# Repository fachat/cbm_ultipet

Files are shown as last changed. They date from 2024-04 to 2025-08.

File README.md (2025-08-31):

# Ulti-PET

Note: this is a part of a larger set of repositories, with [upet_family](https://github.com/fachat/upet_family) as the main repository.

This is a re-incarnation of the Commodore PET computer(s) from the later 1970s.

It is build on a PCB that fits into a C64-II case (with extra cutouts for connectors), and has only parts that can still be obtained new in 2024/2025.
A 3D-printed case is also available specific for the Ulti-PET PCB.

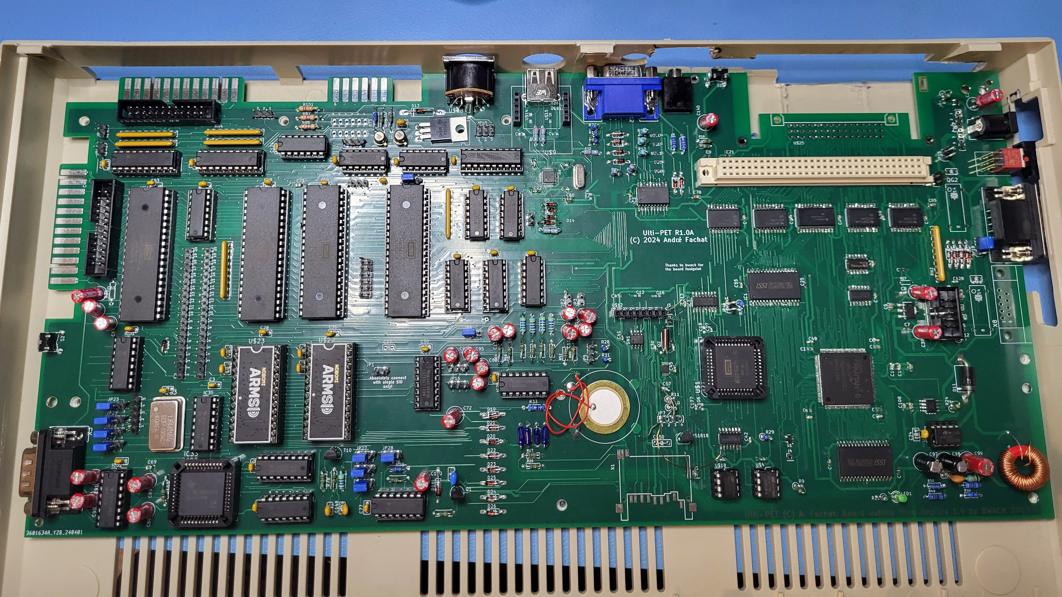
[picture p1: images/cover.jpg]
Picture of a Ulti-PET


Videos on the machine are coming soon on the [YouTube 8-bit times](https://youtube.com/playlist?list=PLi1dzy7kw1iybjcUccgjCV4fhNH4IPWSx) channel.

## Features

The board is built with a number of features:

- Commodore 3032 / 4032 / 8032 / 8296 with options menu to select at boot
  - Boot-menu to select different PET versions to run (BASIC 1, 2, 4)
  - 40 and 80 col character display
  - 8296 memory map emulation
  - IEEE488 interface (card edge and 24pin flat ribbon cable)
  - Tape connector (card edge, incl. 9V for proper tape operation)
  - PET graphics keyboard, or alternatively a C64 keyboard
- Improved system design:
  - 512k video RAM, plus 512k fast RAM, accessible using banks on the W65816 CPU
  - boot from an SPI Flash ROM
  - up to 13.5 MHz mode (via configuration register)
  - Write protection for the PET ROMs once copied to RAM
  - lower 32k RAM mappable from all of the 512k fast RAM
  - single 5V power supply (<1A) using USB-C connector
  - hardware and firmware support SD-Card and USB keyboard or mouse
- Improved Audio output:
  - Original beeper sound
  - Audio output using a DAC with DMA
  - Dual SID output
  - beeper, DAC, and SID are mixed into a stereo line output
  - integrated amplifier can drive <1W speakers
- Improved Video output:
  - VGA colour video output (222 RGB)
  - up to 96x72 characters on screen
  - hires modes up to a 720x576 resolution
  - Dual 16 out of 64 colour palette, Colour-PET or C128 VDC-compatible, Sprites
  - Hires graphics mode (using a configuration register)
  - modifyable character set
  - multiple video pages mappable to $8000 video mem address
- Extra I/O features:
  - Userport Joystick, software-switchable between single and dual joystick configs
  - fast serial IEC for Commodore's 1581 or 1571 disk drives (ROM support TBD)
  - 5V SPI interface for further extensions
  - 3.3V SPI interface for further extensions
  - Adafruit(tm) UEXT interface for further extensions (SPI shared with 3.3V SPI, includes I2C)
  - Dual UART serial, one RS232, one TTL (shared with UEXT, or the USB-C-to-serial)

## Overview

The system architecture is actually rather simple, as you can see in the following graphics.

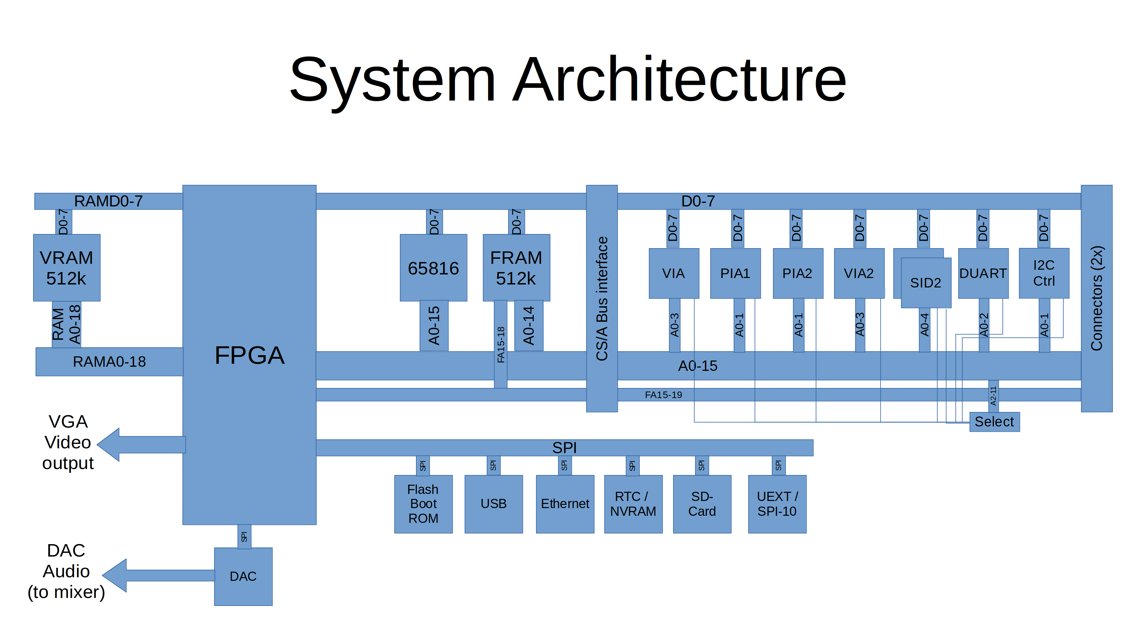
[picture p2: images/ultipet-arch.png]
Ulti-PET System Architecture


The main functionality is "hidden" inside the FPGA. It does:

1. clock generation and management
2. memory mapping
3. video generation.
4. SPI interface and boot
5. DAC DMA

On the CPU side of the FPGA it is actually a rather almost normal 65816 computer, 
with the exception that the bank register (that catches and stores the address lines 
A16-23 from the CPU's data bus) is in the FPGA, and that there is no ROM. The ROM has been
replaced with some code in the FPGA that copies the initial program to the CPU accessible
RAM, taking it from the Flash Boot ROM via SPI. This actually simplifies the design,
as 

1. parallel ROMs are getting harder to come by and
2. they are typically not as fast as is needed, and
3. with the SPI boot they don't occupy valuable CPU address space.

The video generation is done using time-sharing access to the video RAM.
The VGA output is 720x576 at 50Hz, or 720x480 at 60 Hz. So there is a pixel clock of 27MHz.

The system runs at 13.5MHz, so a byte of pixel output (i.e. eight pixels) has four
memory accesses to VRAM. Two of them are reserved for video access, one for fetching the
character data (e.g. at $08xxx in the PET), and the second one to fetch the "character ROM"
data, i.e. the pixel data for a character. This is also stored in VRAM, and is being loaded
there from the Flash Boot ROM by the initial boot loader.

The FPGA reads the character data, stores it to fetch the character pixel data, and streams
that out using its internal video shift register.

For more detailled descriptions of the features and how to use them, pls see the 
[FPGA repository](https://github.com/fachat/upet_fpga) that contains the code for the FPGA,
as described in the next section.

## I/O included in the Ulti-PET

The Ulti-PET not just has the Ultra-CPU, but also loads of I/O on the one board:

### Standard PET IO

The Ulti-PET includes the standard PET I/O features using the VIA and two PIAs, with some extensions. So, it has:

- IEEE488, including flat ribbon cable and card edge connector; with the additional capability of working as a device too
- Tape#1 (incl. 9V for proper tape operation), incl. card edge connector
- Tape#2 as TTL, but normally re-used for IEEE488 device handling
- PET keyboard, with the option to use a C64 keyboard, and the extended Ultipet-Keyboard
- PET userport, with the Video signal (optionally) replaced with 5V to accomodate user port extensions; incl. card edge connector
- Joystick connectors for the userport, software-switchable between single- or dual mode (compatible with 'stupid pet tricks')
- Reset and diag push buttons

### RS232

A Dual UART chip provides two serial interfaces. One interface is a real RS232 with a
DB9 connector. The other one is TTL level interface (shared with UEXT, see below).

The USB-C power connector has an USB-to-serial converter, that can be jumpered to the 
TTL level interface.

### Fast IEC

An IEC interface is provided using a second VIA chip. Using the VIA shift register, fast mode IEC
(like in the C128) is implemented.

### Dual SID and sound mixer

Two SID chips are included for your stereo sound pleasure.

The two SID outputs are mixed with the DAC audio output from the Ultra-CPU base.
Also, the beeper sound is mixed into the overall sound output.

Two audio amps are included to, so speakers can be directly connected to the board
(switched off when the audio jack is used).

### Keyboard shift lock and reset

When the shift-lock key in the replacement keyboard is defined on a specific position in 
the keyboard matrix (as is in the keyboard designed by Steve Gray), the key works like a shift-lock key.

In addition, pressing the shift-lock key longer (a few seconds), resets the machine 
(as long as the keyboard scanning still works).

### CS/A expansion board

The board has a full width CS/A slot for a single expansion card, plus a short CS/A board for
the accompanying [CS/A Ultrabus]() Ultra-Bus expansion board. This allows using (compatible)
Apple-II, RC2014, and C64 cartridges with the Ulti-PET.

(Older versions up to 1.2a had a problem there that is now fixed!)

### UEXT, and SPI-10 connectors

The board provides three standard I/O ports:

1. UEXT - this includes serial (see above), I2C, and SPI, all in 3.3V
2. SPI-10-3.3V - a 3.3V SPI interface for external modules (shared with UEXT)
3. SPI-10-5V - a 5V SPI interface provided by the second VIA, with selectable clock mode.

For the SPI-10 connectors see [here](http://forum.6502.org/viewtopic.php?f=4&t=4264&start=15#p48167).
For the UEXT connector see the Olimex [UEXT page](https://www.olimex.com/Products/Modules/UEXT/)

## Firmware features

Of the modern I/O, currently these are included and supported in the firmware, i.e. in the
BASIC4 models:

- USB keyboard or mouse support, if you select the boot option with a USB keyboard
- SD-Card support using the SD-Card filesystem from the Commander X16 provided by Michael Steil.
- C64 compatible kernal jump table

Note that if you select the boot option while holding the left shift key, a second optional 
configuration is being used.
For more details see the [ROM](https://github.com/fachat/upet_roms) repository, that contains
the current version of the firmware and accompanying documentation.
 
## Known Issues

The current revision is 1.3A

The known issues from the 1.2A version have been fixed.

A small number of non-functional issues has been found and documented. See the
[github list of issues](https://github.com/fachat/cbm_ultipet/issues?q=is%3Aissue%20state%3Aopen%20label%3Ar1.3a).

## Revision history

1.3a: Update:
- fixes for 1.2a known issues included, including improved audio mixer
- USB-C power supply connector, with USB-to-serial converter that can be connected to the internal 2nd serial port
- footprints for Joysticks improved and moved inwards
- footprint for VGA connector improved
- extended keyboard connector with I2C, and other lines
- extended pin header connectors for RS232
- improved pinout on FPGA to prep for HDMI (video output on differential pairs)
- optional pulldowns on audio out for original SIDs
- (most) THT parts have proper part numbers for JLCPCB for outsourced assembly too, not just SMD

1.2a: Update
- separate 3.3V generation for the bus, USB, and network, more bypass for SD cards
- Power, Shift Lock LED
- Remove 2nd oscillator option
- Digital video out connector for further experimentation
- Fix addressing of 2nd SID
- Replace some 1N4148 with 1N4448 for lower drop voltage, fix joystick diode direction
- Dual voltage divider for TTL beeper to avoid left/right audio crosstalk
- Fixes on the UART

1.1a: Update:
- Fixed userport joystick handling, allow software switching between single- and dual mode
- Include the beeper into the sound mixer
- Move from single UART to dual UART, to provide TTL serial or serial for UEXT
- Add I2C controller for UEXT
- Add UEXT, SPI-10-3.3V, SPI-10-5V connectors
- Add SPI interface with selectable modes on the second VIA (shares shift register with fast serial IEC bus)

1.0a: Initial release

## Building

Here are the subdirectories:

- [Board](Board/) that contains the board schematics and layout

Note that a case for the Ulti-PET is in the works - the case modifications for the Micro-PET do *not* work.

In addition, two other repositories are needed - they are separate as they are shared with other variants of the upet-family:

- [FPGA](https://github.com/fachat/upet_fpga) contains the VHDL code to program the FPGA logic chip used, and describes the configuration options - including the SPI usage, the DAC usage, and the Video features.
- [ROM](https://github.com/fachat/upet_roms) ROM contents to boot

### Board

To have the board built, you can use the gerbers that are stored in the zip file in the Board/production subdirectory.

To populate the board, there is an interactive bom (bill of materials) from KiCad, as well as the KiCad BOM CSV export in the [bom](Board/bom/) folder.

Parts numbers can be found in the [BOM list](Board/bom/cbm_ultipet_v1.2a-bom.xlsx). It has parts numbers for Mouser for all parts (except the SID), 
and for JLCPCB for the SMD parts. You can have JLCPCB assemble most of the SMD parts, and order the rest from Mouser. (Note, to not order parts twice, best
remove the JLPCB assembled parts before you upload to Mouser).

The BOM contains an Ethernet breakout board that is put into the connectors "above" the USB port. As an alternative you could use the 
[Wifi breakout board](https://github.com/fachat/upet_wifi). Note that at this time, this is not tested / programmed yet.

As an audio solution I am planning to use the Visaton K40SQ speakers, if you want to order them as well.

### FPGA

The FPGA is a Xilinx Spartan 6 programmable logic chip. It runs on 1.2V with 3.3V I/O and I programmed it in VHDL.

To build the FPGA content, clone the [FPGA](https://github.com/fachat/upet_fpga) repository, and look for the ultipetx.yz.bin, where the x.yz should be replaced with the current board
version, or the highest FPGA version below the board version.
This needs to be programmed into the SPI flash chip containing the configration for the FPGA.

To actually modify the code, you have to download and install the Xilinx WebISE software and open the ultipetx.yz.xise project file.

### ROM

To build the boot ROM image, clone the [ROM](https://github.com/fachat/upet_roms) repository, and build the spiimg70m file. This needs to be 
programmed into the SPI flash ROM containing the 65816 boot code.

The ROM image can be built using gcc, xa65, and make. Use your favourite EPROM programmer to burn it into the SPI Flash chip.

The ROM contains images of all required ROM images for BASIC 1, 2, and 4, and corresponding editor ROMs, including
some that have been extended with wedges.

The updated editor ROMs are from [Steve's Editor ROM project](http://www.6502.org/users/sjgray/projects/editrom/index.html) and can handle C64 keyboards, has a DOS wedge included, and resets into the Micro-PET boot menu.
For more details see the description in the ROM repository.

### Case

Currently no custom case is publicly available. I just didn't have time to build / test / write up the ones I have on tinkercad. Contact me privately and I can provide you a link.

## Gallery (R1.0)

The boot menu

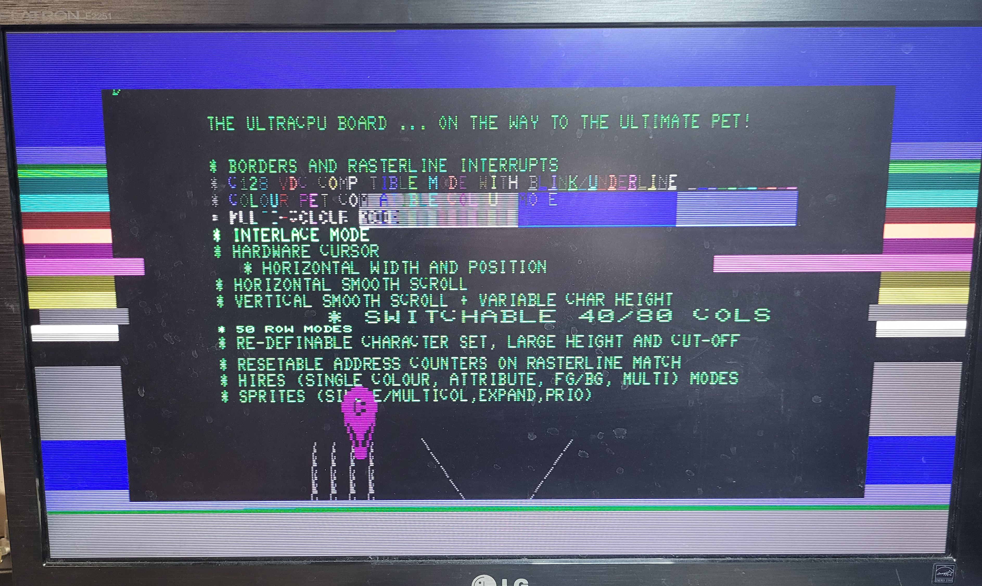
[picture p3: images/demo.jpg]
Demo of graphics capabilities


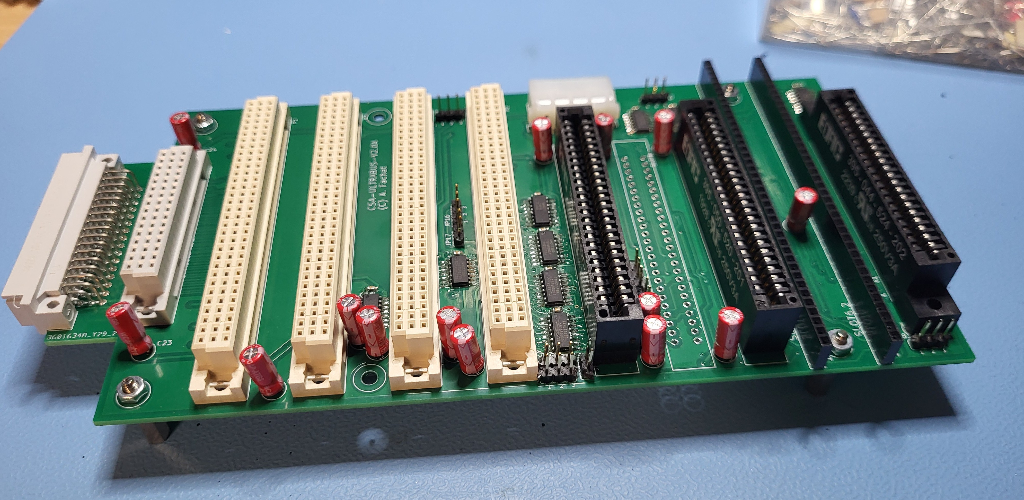
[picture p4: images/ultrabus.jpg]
Expansion bus


First showing the boot menu during the build process

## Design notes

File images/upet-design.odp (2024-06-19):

## System Architecture

A0-3

A0-1

A0-1

FA15-18

A0-15

D0-7

D0-7

D0-7

D0-7

D0-7

D0-7

D0-7

D0-7

SPI

SPI

SPI

SPI

SPI

SPI

SPI

D0-7

RAM
A0-18

D0-7

CS/A Bus interface

A0-3

A0-4

A0-2

A0-14

A0-1

Connectors (2x)

A2-11

RAMD0-7

FPGA

D0-7

VRAM

512k

65816

FRAM

512k

VIA

PIA1

PIA2

VIA2

SID1

SID2

DUART

I2C

Ctrl

RAMA0-18

VGA

Video

output

DAC

Audio

(to mixer)

A0-15

FA15-19

SPI

Select

Flash
Boot
ROM

USB

Ethernet

RTC /
NVRAM

SD-
Card

UEXT /

SPI-10

DAC

## Memory Map (boot)

ipl

ipl

CPU address space (lower 1M)

64k
bank0

Banks 0 … 7

Banks 8 … 15

64k
bank0

64k 8296

Ext. bank

Banks 2 … 7

64k video
bank

Banks 9 … 15

512k FRAM

Physical address space

The CPLD can only write (the IPL code from Flash) to VRAM, so the initial

Mapping maps VRAM to banks 0-7 of the CPU

512k VRAM

## Memory Map

CPU address space (lower 1M)

0-32k

32-
64k

Banks 1 … 15

Any of 16

32k blocks

In FRAM

4k
V

Bank 0, or

8296 mem expansion

In bank 1

Any of four 2k positions in video bank

8k
Chr

rom

8k
Chr

64k
bank0

64k 8296

Ext. bank

Banks 2 … 7

64k video
bank

Banks 9 … 15

512k FRAM

Physical address space

512k VRAM

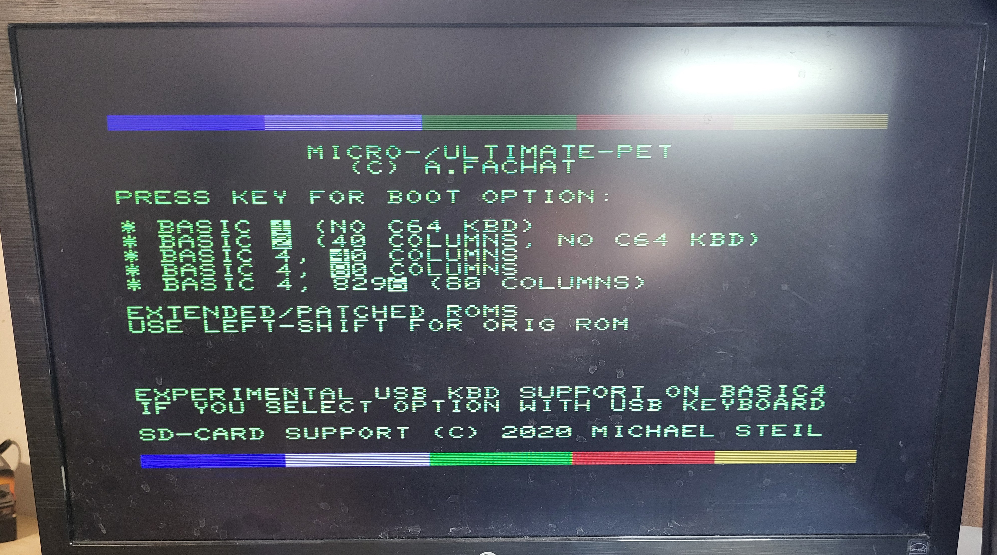
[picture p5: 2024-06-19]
images/boot_menu.jpg

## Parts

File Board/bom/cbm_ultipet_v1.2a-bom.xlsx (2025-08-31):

Id | Designator | Footprint | Quantity | Orig. Quantity | Designation | Supplier and ref | MOUSER | Manufac. Part | Alt. Mouser | Alt. Manufac. Part | JLCPCB Part #（optional）
 | SMD
81 | U$19 | TQFP144 | 1 |  | XC6SLX9-TQG144 |  | 217-XC6SLX9-2TQG144C | XC6SLX9-2TQG144C |  |  | C415799
68 | IC8 | PQFP-32_5x5mm_P0.5mm | 1 |  | MAX3421E |  | 700-MAX3421EEHJT | MAX3421EEHJ+T |  |  | C2651881
150 | Q4 | MICRO3 | 1 |  | IRLML5203 |  | 942-IRLML5203TRPBF | IRLML5203TRPBF |  |  | C2592
59 | SN1 | SOIC8 | 1 |  | MCP48X2 |  | 579-MCP4802-E/SN | MCP4802-E/SN |  |  | C144363
148 | U$13 | MSOP10 | 1 |  | MCP79510 |  | 579-MCP79510-I/MS | MCP79510-I/MS |  |  | C636437
70 | IC24 | TSSOP-20_4.4x6.5mm_P0.65mm | 1 |  | PCF9564 |  | 771-PCA9564PW118 | PCA9564PW,118
20 | C40,C29,C30,C39 | C0603 | 4 |  | 18p |  | 80-C0603C180K4HACTU | C0603C180K4HACTU |  |  | C152921
5 | C2, C11,C12,C13, C15,C16,C17,C18,C19, C22, C23, C25,C26,C27, C31,C32,C33,C34,C35, C41,C42,C43,C44,C45,C46,C47,C48, C58, C100,C101,C102,C103,C104,C105,C106,C107,C108,C109,C110,C111,C112,C113, C146, C147, C150,C7,C8,C63,C85,C127,C128,C152,C155 | C0603 | 53 |  | 0.1u |  | 710-885012206020 | 885012206020 |  |  | C14663
21 | C5,C67,C68,C69,C70,C71,C64,C65,C66,C154 | C0805 | 9 |  | 22u |  | 187-CL21A226MPQNNNE | CL21A226MPQNNNE |  |  | C5674
67 | C1,C4,C14,C24,C49,C54,C55,C56,C57,C120,C121,C123 | C0603 | 12 |  | 1u |  | 791-0603B105K6R3CT | 0603B105K6R3CT | 80-C0603X105J8R | C0603X105J8RACTU | C309479
 | U8 |  | 1 |  | 74ahct1g08 |  | 595-74AHCT1G08DBVRG4 | 74AHCT1G08DBVRG4 |  |  | C113521
109 | U1 | SOT-23-5 | 1 |  | 74LVC1G04 |  | 595-SN74LVC1G04DBVR | SN74LVC1G04DBVR |  |  | C7434171
93 | IC5,IC2,IC4 | SO20W@1 | 3 |  | 74245DW |  | 595-SN74HCT245DWR | SN74HCT245DWR |  |  | C132267
86 | IC16 | SO24L | 1 |  | 74LVC8T245SO24 |  | 595-SN74LVC4245ADW | SN74LVC4245ADW |  |  | C2677625
64 | IC19,IC13 | SO20W@1 | 2 |  | 74244DW |  | 595-SN74HCT244DWRG4 | SN74HCT244DWRG4 |  |  | C6776
49 | U5,U4 | SOIC-16 | 2 |  | CD4053B |  | 595-CD4053BNSR | CD4053BNSR |  |  | C6742
152 | IC14 | SO14 | 1 |  | 7414D |  | 595-SN74LV14ADR | SN74LV14ADR |  |  | C133541
57 | IC18 | SO14 | 1 |  | 7406D |  | 595-SN74LVC06ADR | SN74LVC06ADR |  |  | C7658
107 | IC7 | SO16 | 1 |  | 74138D |  | 771-74LVC138AD-T | 74LVC138AD,118 |  |  | C6061
72 | IC3 | SO14@1 | 1 |  | 74125D |  | 595-SN74LVC125AD | SN74LVC125AD |  |  | C6057
3 | U$16 | PSOP-8-FIXED | 1 |  | AP2132BB |  | 621-AP2132BMP1.2TRG1 | AP2132BMP-1.2TRG1 |  |  | C338874
116 | U$3,U$17 | SOT223 | 2 |  | LDI1117 |  | 637-LDI1117-3.3H | LDI1117-3.3H |  |  | C6186
38 | U$14,U$6,U$10,U$5,U$8,U$11,U$15 | SOD323 | 7 |  | ESDBIDIR |  | 771-PESD5V0L1BA-T/R | PESD5V0L1BA,115 |  |  | C2687118
63 | IC1,IC10 | SOP32 | 2 |  | RAMSOCK32TO512KSOP |  | 870-61C5128AS-25QLI | IS61C5128AS-25QLI
 | Pin header
4 | P2 | C64KEYB | 0 | 1 | C64KEYB
143 | P8 | C64KEYB | 0 | 1 | PETKEYBD
11 | JP17,JP2,JP6,JP15,JP18,JP11,JP9,JP4,JP12,JP3,JP1 | JP1 | 0 | 11 | JP1E
26 | JP8,JP5,JP13,JP27,JP29,JP31,JP26,JP14,JP20,JP16,JP28,JP24 | JP2 | 0 | 9 | JP2E
35 | J4,J5,J1,J3 | PinHeader_1x01_P2.54mm_Vertical | 0 | 4 | Conn_01x01_Pin
75 | U$26 | JP7 | 0 | 1 | JP7
77 | P6,P7 | JP6 | 0 | 2 | CBMTAPE
112 | JP7 | JP4 | 0 | 1 | JP4E
117 | U$27,U$2 | JP5 | 0 | 2 | JP5
 |  |  | 10 |  | pin strip straight 20 pin |  | 538-22-28-4204 | 22-28-4204 | 649-1012937892001BLF | 10129378-920001BLF
42 | P4,P9 | IDC-Header_2x05_P2.54mm_Vertical | 2 |  | ~ |  | 710-61201021621 | 61201021621
128 | J7 | IDC-Header_2x05_P2.54mm_Vertical | 1 |  | UEXT_Host |  | 710-61201021621 | 61201021621
151 | U$7 | FLAT10BOX | 1 |  | XILINXPROG (optional) |  | 710-61201021621 | 61201021621
78 | J8 | PinHeader_2x04_P2.54mm_Vertical | 0 | 1 | Conn_02x04_Odd_Even
139 | JP10 | JP3Q | 0 | 1 | JP3Q
 | P11 | PinHeader_2x06_P2.54mm_Vertical |  | 1
 |  |  | 1 |  |  |  | 649-1012938192001BLF | 10129381-920001BLF
142 | P3 | FLAT24 | 1 |  | IEEE488FLATCABLE |  | 710-61202421621 | 61202421621
95 | P5 | FLAT24 | 1 |  | PETUSERPORT |  | 710-61202421621 | 61202421621
85 | SJ1 | SJ_2 | 1 |  | SJ2W |  |  | Solder-Jumper, no part
130 | C114 | C025-024X044 | 1 |  | 1500p |  | 594-D152K25Y5PH63J5R | D152K25Y5PH63J5R
120 | C125 | C025-024X044 | 1 |  | 0.01, 50V |  | 594-K103K15X7RF5TH5 | K103K15X7RF5TH5 | flat disk
8 | C149,C148 | C025-024X044 | 2 |  | 0.01u |  | 594-K103K15X7RF5TH5 | K103K15X7RF5TH5 | flat disk
137 | C126 | C025-025X050 | 1 |  | 0.47 |  | 810-FA26X7R1H474KNU6 | FA26X7R1H474KNU06 | flat disk
25 | C138,C94,C133,C143,C124,C134,C137,C144,C131,C139,C141,C93,C92,C84,C135,C142,C73,C132,C145 | C025-024X044 | 19 |  | 100n |  | 594-K104K10X7RF53L2 | K104K10X7RF53L2 | 594-K104K15X7RF53H5 | K104K15X7RF53H5
33 | C74,C3,C77,C36,C76,C59,C62,C20,C50,C28,C10,C51,C52,C37,C53,C60 | C025-025X050 | 17 |  | 100n |  | 594-K104K10X7RF53L2 | K104K10X7RF53L2 | 594-K104K15X7RF53H5 | K104K15X7RF53H5
96 | C86,C90,C91,C87 | E2,5-6 | 4 |  | 1u |  | 710-860010772005 | 860010772005 | 710-860020672005 | 860020672005
 | C158,C159 | CP_Radial_D5.0mm_P2.50mm | 2 |  | 100u |  | 710-860010372006 | 860010372006
9 | C151,C61,C6,C153 | E2,5-6 | 4 |  | 47u |  | 710-860010372004 | 860010372004
 | C156,C157 | C_Disc_D5.0mm_W2.5mm_P5.00mm | 2 |  | 10u |  | 810-FG28X5R1E106MR06 | FG28X5R1E106MRT06
28 | C81,C79,C78,C80 | C025-025X050 | 4 |  | 22000 (only if real SIDs) |  | 594-K222K15X7RF5TH5 | K222K15X7RF5TH5
 | C129,C136 | C_Disc_D5.0mm_W2.5mm_P5.00mm | 2 |  | 1u MLCC |  | 810-FG28X5R1H105KRT0 | FG28X5R1H105KRT00
45 | C117,C96,C95,C116,C118,C115 | E2-5 | 6 |  | 1u (note: alternatively mlcc) |  | 810-FG28X5R1H105KRT0 | FG28X5R1H105KRT00 | 710-860020672005 | 860020672005
39 | C88,C89 | E2,5-6 | 2 |  | 4u7 |  | 710-860020472001 | 860020472001
134 | C130 | E2-4 | 1 |  | 10u |  | 710-860020372001 | 860020372001
103 | C83,C119,C82,C122 | E2-5 | 4 |  | 10u |  | 710-860020372001 | 860020372001
53 | C38 | E2,5-6 | 1 |  | 22u |  | 710-860010372002 | 860010372002
65 | C72,C75,C140 | E2,5-7 | 3 |  | 47u |  | 710-860010372004 | 860010372004
80 | C97,C98,C9,C21 | E2,5-7 | 4 |  | 100u |  | 710-860010372006 | 860010372006 | 667-EEU-FM1E101 | EEU-FM1E101
131 | C99 | E2,5-7 | 1 |  | 330u |  | 710-860020373011 | 860020373011
140 | L4 | TJ4-U2 | 1 |  | 200uH |  | 710-744115 | 744115
147 | L2 | 0204_7@1 | 1 |  | 1uH |  | 652-78F1R0K-TR-RC | 78F1R0K-TR-RC
6 | T6,T7 | TO92 | 2 |  | 2T2222 |  | 637-2N2222A | 2N2222A | 494-JAN2N2222A | Jan2N2222A
74 | Q1 | TO92 | 1 |  | BC557 |  | 512-BC557BTA | BC557BTA
125 | T10 | TO92 | 1 |  | BC547 |  | 512-BC547BTA | BC547BTA
135 | T8 | TO220 | 1 |  | TIP31 |  | 863-TIP31CG | TIP31CG
92 | R49 | 0204_7 | 1 |  | 0.22 |  | 603-MFR-25FTF52-0R22 | MFR-25FTF52-0R22
12 | R33 | 0207_10 | 1 |  | 10 |  | 603-MF0207FTE26-10R | MF0207FTE26-10R
24 | R2,R1,R4 | 0204_7 | 3 |  | 33 |  | 660-MF1/4LCT52R330J | MF1/4LCT52R330J
44 | R7,R8 | 0204V | 2 |  | 68 |  | 660-MF1/4LCT52R680G | MF1/4LCT52R680G
84 | R28,R31,R26 | 0204V | 3 |  | 100 |  | 603-MFR-12FTF52-100R | MFR-12FTF52-100R
146 | R50 | 0204_7 | 1 |  | 180 |  | 603-MFR-12FTF52-180R | MFR-12FTF52-180R
56 | R29 | 0207_2V | 1 |  | 330 |  | 603-MFR-12FTF52-330R | MFR-12FTF52-330R
55 | R17,R22 | 0207_2V | 2 |  | 390 |  | 756-MFR3-390RFC | MFR3-390RFC | 603-MFR-25FBF52-390R | MFR-25FBF52-390R
32 | R55,R67,R21,R32,R59,R63 | 0204_7 | 6 |  | 470 |  | 708-RNF14FTD470R | RNF14FTD470R
40 | R81 | 0207_7 | 1 |  | 470 |  | 708-RNF14FTD470R | RNF14FTD470R
113 | R13,R14,R15 | 0204V | 3 |  | 470 |  | 708-RNF14FTD470R | RNF14FTD470R
153 | R73 | 0207_10 | 1 |  | 1k |  | 603-MFR-12FRF521K | MFR-12FRF52-1K | 603-MFR-12FTF52-1K | MFR-12FTF52-1K
110 | R5 | 0207_2V | 1 |  | 1k |  | 603-MFR-12FRF521K | MFR-12FRF52-1K | 603-MFR-12FTF52-1K | MFR-12FTF52-1K
111 | R19,R18,R37,R20 | 0204V | 4 |  | 1k |  | 603-MFR-12FRF521K | MFR-12FRF52-1K | 603-MFR-12FTF52-1K | MFR-12FTF52-1K
100 | RG0 | 0204_7 | 1 |  | 1k1 |  | 603-MFR-25FTE52-1K1 | MFR-25FTE52-1K1
104 | R38 | 0204V | 1 |  | 1k5 |  | 603-MFR-12FTF52-1K5 | MFR-12FTF52-1K5
157 | R12 | 0207_2V | 1 |  | 1k5 |  | 603-MFR-12FTF52-1K5 | MFR-12FTF52-1K5
41 | R36,R23 | 0204V | 2 |  | 2k2 |  | 603-MFR-12FTF52-2K2 | MFR-12FTF52-2K2
62 | R25,R3,R27 | 0207_2V | 3 |  | 4k7 |  | 603-MFR25SFRF52-4K7 | MFR25SFRF52-4K7 | 603-MFR-12FTF52-4K7 | MFR-12FTF52-4K7
17 | RS0 | 0204_7 | 1 |  | 6k8 |  | 603-MFR-12FTF52-6K8 | MFR-12FTF52-6K8
105 | R16,R6 | 0204_5 | 2 |  | 10k |  | 756-MFR3-10KFC | MFR3-10KFC
15 | R10,R30,R11,R24,R9 | 0207_2V | 5 |  | 10k |  | 756-MFR3-10KFC | MFR3-10KFC
71 | R78 | 0207_7 | 1 |  | 10k |  | 756-MFR3-10KFC | MFR3-10KFC
52 | R5,R12,R74,R75 | 0207_10 | 2 |  | 10k |  | 756-MFR3-10KFC | MFR3-10KFC
129 | R76 | 0207_7 | 1 |  | 15k |  | 603-MFR-12FTF52-15K | MFR-12FTF52-15K
51 | R68,R69 | 0204_7 | 2 |  | 47k |  | 603-MFR-25FRF52-47K5 | MFR-25FRF52-47K | 603-MFR-25FRF52-47K
108 | R48 | 0207_2V | 1 |  | 100k |  | 756-MFR3-100KFC | MFR3-100KFC
13 | R62,R58,R54,R66,R60,R52,R56,R64 | 0204_7 | 8 |  | 100k |  | 756-MFR3-100KFC | MFR3-100KFC
36 | R79,R77,R80 | 0207_7 | 3 |  | 100k |  | 756-MFR3-100KFC | MFR3-100KFC
10 | R57,R65,R53,R61 | 0204_7 | 4 |  | 10M |  | 71-CMF55-G-10M/R | CMF5510M000GKR6 | 603-MF0204FTE52-10M | MF0204FTE52-10M
19 | RV1 | RK12L12_horizontal | 1 |  | R_Potentiometer_Dual |  | 688-RK12L12C0C0V | RK12L12C0C0V
54 | RN2,RN1 | RN-9 | 2 |  | 10k |  | 652-4609X-1LF-10K | 4609X-101-103LF
22 | RN4,RN6 | RN-9 | 2 |  | 5k1 |  | 652-4609X-101-512LF | 4609X-101-512LF
46 | RN5,RN3 | RN-9 | 2 |  | 2k4 |  | 652-4609X-AP1-222LF | 4609X-AP1-222LF | 652-4609X-1LF-2.2K | 4609X-101-222LF
88 | RN7 | RN-8 | 1 |  | 4k7 |  | 652-4608X-AP1-472LF | 4608X-AP1-472LF | 652-4608X-1LF-4.7K | 4608X-101-472LF
29 | RN8 | RN-8 | 1 |  | 10k |  | 652-4608X-1LF-10K | 4608X-101-103LF
1 | IC48 | DIL14 | 1 |  | 7414N |  | 595-SN74HCT14N | SN74HCT14N
 | IC6 | PLCC44 | 1 |  | TL16C255 |  | 595-TL16C2552FNR | TL16C2552FNR
18 | IC21 | DIL14 | 1 |  | 7417N |  | 595-SN74LS07N | SN74LS07N
14 | IC17,IC20 | DIL40 | 2 |  | PIA |  | 955-W65C21N6TPG-14 | W65C21N6TPG-14
7 | U$24 | DIL08 | 1 |  | MC34063A |  | 511-MC34063ACN | MC34063ACN
30 | U7,U6 | DIP-8_W7.62mm_Socket_LongPads | 2 |  | LM386 |  | 926-LM386N-3/NOPB | LM386N-3/NOPB
43 | U$4,U$18 | DIL08 | 2 |  | SPIFLASH |  | 804-25VF080B5CPAE | SST25VF080B-50-4C-PAE
47 | U$23,U$22 | DIL28 | 2 |  | SID
66 | U$21,U$20 | DIL20 | 2 |  | 74LS641 |  | 595-SN74LS641-1N | SN74LS641-1N
76 | IC23 | DIL14 | 1 |  | 7486N |  | 595-CD74HCT86EE4 | CD74HCT86EE4
73 | IC31,IC32 | DIL16 | 2 |  | MAX232 |  | 595-MAX232N | MAX232N
90 | IC36,IC15 | DIL40 | 2 |  | VIA |  | 955-W65C22N6TPG-14 | W65C22N6TPG-14
97 | IC29 | DIL14 | 1 |  | 556N |  | 595-NE556N | NE556N
101 | IC9,IC28,IC11,IC35 | DIL16 | 4 |  | 74138N |  | 595-SN74HCT138N | SN74HCT138N
106 | IC34 | DIL14 | 1 |  | 7406N |  | 595-SN74LS06NE4 | SN74LS06NE4 | 595-SN74LS06N | SN74LS06N
114 | U2 | DIP-14_W7.62mm_LongPads | 1 |  | 74HCT164 |  | 595-CD74HCT164E | CD74HCT164E
118 | IC22 | DIL14 | 1 |  | 7400N |  | 595-SN74HCT00N | SN74HCT00N
119 | U3 | DIL14 | 1 |  | 74HCT00 |  | 595-SN74HCT00N | SN74HCT00N
124 | IC49 | DIL20 | 1 |  | 74241N |  | 595-CD74HCT241E | CD74HCT241E
127 | IC40,IC27 | DIL14 | 2 |  | 7474N |  | 595-SN74HCT74N | SN74HCT74N
132 | IC26 | DIL14 | 1 |  | LM3900N |  | 595-LM3900NE4 | LM3900NE4
133 | IC25 | DIL16 | 1 |  | 74139N |  | 595-SN74HCT139N | SN74HCT139N
138 | DS1818 | TO92 | 1 |  | DS1813 |  | 700-DS1818-10T&R | DS1818-10+T&R
141 | U$1 | PLCC44 | 1 |  | W65C816SPLCC |  | 955-W65C816S6PLG-14 | W65C816S6PLG-14
145 | IC12 | DIL16 | 1 |  | 74145N |  | 595-SN74LS145N | SN74LS145N | 595-SN74LS145NE4 | SN74LS145NE4
 |  |  | 4 |  | Socket 40 pin |  | 571-1-2199299-5 | 1-2199299-5
 |  |  | 2 |  | Socket 28 pin |  | 571-1-2199299-2 | 1-2199299-2
 |  |  | 3 |  | Socket 20 pin |  | 571-1-2199298-6 | 1-2199298-6
 |  |  | 8 |  | Socket 16 pin |  | 571-1-2199298-4 | 1-2199298-4
 |  |  | 11 |  | Socket 14 pin |  | 737-ICS-314-T | ICS-314-T | 571-1-2199298-3 | 1-2199298-3
 |  |  | 5 |  | Socker 8 pin |  | 571-1-2199298-2 | 1-2199298-2
 |  |  | 2 |  | Socket 44 pin PLCC |  | 517-8444-11B1-RK-TP | 8444-11B1-RK-TP | 737-PLCC-44-AT | PLCC-44-AT
98 | X4 | 1503_09 | 1 |  | 1503_09 |  | 490-SJ1-3515N | SJ1-3515N
16 | X7,X8 | 182-009-MALE | 2 |  | M09-182 |  | 523-L717SDE09P1ACH | L717SDE09P1ACH
60 | CN2 | MA156_6-2_KEYED | 0 | 1 | PORT_CASSETTE_EDGE |  |  | footprint only, no part
82 | X3 | M09HP | 1 |  | M09HPS |  | 523-G17C0910132EU | G17C0910132EU
83 | U$25 | FABC48R2 | 1 |  | CSASHORTBUSFA |  | 617-09282486804791 | 9282486804791
94 | CN5 | MA156_12-2_USER | 0 | 1 | PORT_USER_PET_EDGE |  |  | footprint only, no part
99 | USB1 | USB-A-H | 1 |  | USB-A-H |  | 710-614004190021 | 614004190021
102 | J2 | DCJ0202 | 1 |  | DCJ0202 |  | 806-KLDX-0202-A | KLDX-0202-A
115 | X2 | HDR15RA | 1 |  | D-SUB15-HDR15RA |  | 523-7HDE15SD1CH4FVGA | L77HDE15SD1CH4FVGA
121 | CN3 | MA156_12-2_IEEE | 0 | 1 | PORT_IEEE_EDGE |  |  | footprint only, no part
144 | U$28 | DIN6PIEC | 1 |  | DINIEC |  | 490-SDF-60J | SDF-60J | 566-MAB6H | MAB 6 H
156 | P1 | CSABUSSOCK180 | 1 |  | CSABUSSOCK180 (optional) |  | 617-09-03-264-6824 | 9032646824 | 649-8609464814T5F1LF | 86094648114T55F1LF
23 | LED1 | LED3MM | 2 |  | LED3MM (Green – power) |  | 696-SSL-LX305F4GD | SSL-LX305F4GD
 |  |  | 1 |  | LED3MM (Red – shift lock) |  | 710-151033RS03000 | 151033RS03000
37 | D19, D20, D21, D22, D23, D24, D25, D26, D5, D6, D8, D18 | DO35-7 | 12 |  | 1N4148DO35-7 |  | 78-1N4148 | 1N4148TR | 512-1N4148 | 1N4148
 | D1, D2, D3, D4, D7, D10, D12, D14, D15, D16, D17, D27, D28, D29, D30, D31, D32, D33, D34, D35, D36, D37, D38, D39, D40, D41, D42, D43, D44, D45, D46, D47 | D_DO-35_SOD27_P7.62mm_Horizontal | 32 |  | 1N4448 |  | 78-1N4448 | 1N4448TR
91 | D11 | DO201-15 | 1 |  | 1N5400 |  | 750-1N5400-G | 1N5400-G
87 | D13 | C1702-15 | 1 |  | 7.5V |  | 610-1N755A | 1N755A TR PBFREE
27 | S2,S1 | B3F-31XX | 2 |  | 31-XX |  | 653-B3F-3122 | B3F-3122
126 | SW1 | SW_E-Switch-400-combined | 1 |  | Alternatively use C64 replacement switch |  | 612-400MSP1R1BLKM7QE | 400MSP1R1BLKM7QE | 612-400AWMDP1R1M6QE | 400AWMDP1R1M6QE
48 | QG3 | SG51 | 1 |  | 1,8432MHz |  | 520-100A-018 | ECS-100A-018
69 | Q2 | TC26H | 1 |  | 32kHz |  | 710-830002995B | 830002995B
79 | JS1 | RENJS6 | 1 |  | RENOSCXLH – 70 MHz |  | 972-XLH536070000000I | XLH536070.000000I
136 | Q3 | HC49_S | 1 |  | 12MHz |  | 549-CYS6Q31C-12MHZ | CYS6Q31C-12.000MHZ
~~149~~ | ~~QG1~~ | ~~SG51~~ | 0 | ~~1~~ | ~~50MHz~~ |  | ~~520-TCF5000-X~~ | ~~ECS-100AX-500~~ | ~~774-MXO45T-3C-50.0~~ | ~~MXO45T-3C-50M0000~~
~~89~~ | ~~U$12~~ | ~~GRAVITECH-SDCARD~~ | 0 | ~~1~~ | ~~SD-CARD-GRAVI~~ |  | ~~992-MICROSD-ADP ~~ | ~~MICROSD-ADP ~~
 |  |  | 1 |  | Sockel |  | 200-BCS108LSTE | BCS-108-L-S-TE
122 | U$9 | ETHOLIENC | 1 |  | ETHOLIENC (optional) |  | 909-ENC28J60-H | ENC28J60-H
 |  |  | 2 |  | Sockel |  | 200-SSW10501TS | SSW-105-01-T-S | 200-BCS105LSTE | BCS-105-L-S-TE
154 | BEEP1 | PIEZOBEEPER | 1 |  | PIEZOBEEPERPIEZO (optional) |  | 253-AE2038E4WA | AE-2038E-4WA
155 | P10 | Pmod-SDCard | 1 |  | ~ |  | 424-410-380 | 410-380
 |  |  | 1 |  | Sockel |  | 200-BCS106FDTE | BCS-106-F-D-TE
 | Test 54 MHz |  | 3 |  |  |  | 710-830207670409 | 830207670409 |  |  | C2831398
 | Test Speaker |  | 2 |  |  |  | 490-CDS-27204-L100 | CDS-27204-L100
 | Test Speaker |  | 2 |  |  |  | 179-CMS32143724SPX8 | CMS-321437-24SP-X8
 | Key switches N-Keyboard (for SJGray PCB) |  |  |  |  |  | 540-MX1A-C1NW | MX1A-C1NW

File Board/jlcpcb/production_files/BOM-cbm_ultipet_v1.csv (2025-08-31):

Comment | Designator | Footprint | LCSC | Quantity
4u7 | C88,C89 | E2,5-6 | C106368 | 2
10u | C119,C122,C130,C82,C83 | E2-5 | C106654 | 5
74AHCT1G08 | U8 | TSOP-5_1.65x3.05mm_P0.95mm | C113521 | 1
100 | R26,R28,R31,R39,R40 | 0207_2V | C119304 | 5
68 | R7,R8 | 0204V | C119315 | 2
4k7 | R25,R27,R3 | 0207_2V | C119339 | 3
10k | R10,R11,R12,R16,R24,R34,R35,R5,R6,R74,R75,R78,R9 | 0207_2V | C119347 | 13
15k | R76 | 0207_7 | C119351 | 1
100K | R52,R54,R56,R58,R60,R62,R64,R66,R77,R79,R80 | 0204_7 | C119369 | 11
180 | R50 | 0204_7 | C119852 | 1
330 | R29 | 0207_2V | C120043 | 1
1k5 | R38 | 0204V | C120059 | 1
4k7 | R43,R44 | 0207_10 | C120071 | 2
6k8 | RS0 | 0204_7 | C129911 | 1
74245DW | IC2,IC4,IC5 | SOP-20_7.5x12.8mm_P1.27mm | C132267 | 3
74LVC14 | IC14 | SO14 | C133541 | 1
TIP31 | T8 | TO220 | C13506 | 1
1k1 | RG0 | 0204_7 | C1367075 | 1
MCP48X2 | SN1 | SOIC8 | C144363 | 1
0.1u | C100,C101,C102,C103,C104,C105,C106,C107,C108,C109,C11,C110,C111,C112,C113,C12,C127,C128,C13,C146,C147,C15,C150,C152,C155,C157,C16,C160,C165,C166,C167,C17,C18,C19,C2,C22,C23,C25,C26,C27,C31,C32,C33,C34,C35,C41,C42,C43,C44,C45,C46,C47,C48,C58,C63,C7,C8,C85 | C0603 | C14663 | 58
1u | C1,C120,C121,C123,C14,C24,C4,C49,C54,C55,C56,C57 | C0603 | C15849 | 12
12MHz | Q3 | HC49_S | C16369 | 1
18p | C29,C30,C39,C40 | C0603 | C1647 | 4
10k | R30,R47,R48 | R_0805_2012Metric_Pad1.20x1.40mm_HandSolder | C17414 | 3
74LVC1G08 | U9 | SOT-23-5 | C19829591 | 1
DS1813 | DS1818 | TO-92_Inline | C2068861 | 1
31-XX | S1,S2 | B3F-31XX | C231320 | 2
VIA | IC15,IC17,IC20,IC36 | DIP-40_W15.24mm_Socket_LongPads | C2332 | 4
JP1E | JP1,JP11,JP12,JP15,JP17,JP18,JP2,JP22,JP23,JP25,JP3,JP4,JP6,JP8,JP9 | JP1 | C234182 | 15
1N4448 | D1,D10,D12,D14,D15,D16,D17,D2,D27,D28,D29,D3,D30,D31,D32,D33,D34,D35,D36,D37,D38,D39,D4,D40,D41,D42,D43,D44,D45,D46,D47,D7 | D_DO-35_SOD27_P7.62mm_Horizontal | C258171 | 32
74LVC8T245SO24 | IC16 | SO24L | C2677625 | 1
PCF9564 | IC24 | TSSOP-20_4.4x6.5mm_P0.65mm | C2678050 | 1
ESDBIDIR | UX10,UX11,UX14,UX15,UX5,UX6,UX8 | SOD323 | C2687118 | 7
100n | C10,C124,C131,C132,C133,C134,C135,C137,C138,C139,C141,C142,C143,C144,C145,C20,C28,C3,C36,C37,C50,C51,C52,C53,C59,C60,C62,C73,C74,C76,C77,C84,C92,C93,C94 | C025-025X050 | C2761728 | 35
SG-8002CE | X1 | Oscillator_SMD_SeikoEpson_SG8002CE-4Pin_3.2x2.5mm | C2831398 | 1
0.01u | C148,C149 | C025-024X044 | C2832505 | 2
10 | R33 | 0207_10 | C2894558 | 1
390 | R17,R22 | 0207_2V | C2894694 | 2
22u | C154,C5,C64,C65,C66,C67,C68,C69,C70,C71 | C0805 | C29277 | 10
32kHz | Q2 | TC26H | C3013591 | 1
5k1 | RN4,RN6 | RN-9 | C30844 | 2
USB-C Power | U11 | USB-C-217180 | C3197940 | 1
10k | RN8 | RN-8 | C33479 | 1
4k7 | RN7 | RN-8 | C33481 | 1
AP2132BB | UX16 | PSOP-8-FIXED | C338874 | 1
CBMTAPE | P6,P7 | JP6 | C37208 | 2
1N4148DO35-10 | D18,D19,D20,D21,D22,D23,D24,D25,D26,D5,D6,D8 | DO35-10 | C402212 | 12
XC6SLX9-TQG144 | UX19 | TQFP-144_20x20mm_P0.5mm | C415799 | 1
470u | C97 | E2,5-7 | C43332 | 1
330u | C99 | E2,5-7 | C442821 | 1
47u | C140,C151,C153,C156,C38,C6,C61,C72,C75 | E2,5-6 | C45101 | 9
MAX3421E | IC8 | LQFP-32_5x5mm_P0.5mm | C45862 | 1
100u | C129,C136,C158,C159,C21,C9,C98 | E2-5 | C47873 | 7
CSASHORTBUSFA | UX25 | FABC48R2-reversed | C5173381 | 1
470 | R13,R14,R15,R21,R32,R55,R59,R63,R67,R81 | 0204V | C5200431 | 10
1N5400 | D11 | DO201-15 | C5359861 | 1
16255 UART | IC6,UX1 | PLCC-44_THT-Socket | C5544025 | 2
512k x8 10ns SRAM | IC1,IC10 | TSOP-II-44_10.16x18.41mm_P0.8mm | C5554776 | 2
UEXT_Host | J7,P4,P9,UX7 | IDC-Header_2x05_P2.54mm_Vertical | C5665 | 4
2k2 | R23,R36 | 0204V | C58682 | 2
JP2E | JP13,JP14,JP16,JP20,JP24,JP26,JP27,JP28,JP29 | JP2 | C587036 | 9
Conn_01x04_Pin | J6,JP19,JP7 | PinHeader_1x04_P2.54mm_Vertical | C587039 | 3
74LVC125D | IC3 | SO14@1 | C6057 | 1
74LVC138D | IC7 | SO16 | C6061 | 1
LDI1117 | UX17,UX3 | SOT223 | C6186 | 2
MCP79510 | UX13 | MSOP10 | C627709 | 1
1u | C115,C116,C117,C118,C86,C87,C90,C91,C95,C96 | E2-5 | C62934 | 10
JP3Q | JP10 | JP3Q | C65114 | 1
CD4053B | U4,U5 | SOIC-16_3.9x9.9mm_P1.27mm | C6742 | 2
74244DW | IC13,IC19 | SOP-20_7.5x12.8mm_P1.27mm | C6776 | 2
33 | R1,R2,R4 | 0204_7 | C713968 | 3
1k | R18,R19,R20,R37,R45,R46,R73 | 0204V | C713997 | 7
5k1 | R41,R42 | 0207_2V | C714010 | 2
220k | R53,R57,R61,R65 | 0204_7 | C714041 | 4
7417N | IC21,IC22,IC23,IC26,IC27,IC29,IC34,IC40,IC48,U2,U3 | DIP-14_W7.62mm_Socket_LongPads | C72114 | 11
74138N | IC11,IC12,IC25,IC28,IC31,IC32,IC35,IC9 | DIP-16_W7.62mm_Socket_LongPads | C72115 | 8
74241N | IC49,UX20,UX21 | DIP-20_W7.62mm_Socket_LongPads | C72118 | 3
SID | UX22,UX23 | DIP-28_W15.24mm_Socket_LongPads | C72121 | 2
LM386 | U6,U7,UX18,UX24,UX4 | DIP-8_W7.62mm_Socket_LongPads | C72124 | 5
74LVC1G04 | U1 | SOT-23-5 | C7434171 | 1
CH340C | U10 | SOIC-16_3.9x9.9mm_P1.27mm | C7464026 | 1
Conn_02x04_Odd_Even | J8 | PinHeader_2x04_P2.54mm_Vertical | C7501275 | 1
~ | P11 | PinHeader_2x06_P2.54mm_Vertical | C7501277 | 1
74LVC06 | IC18 | SO14 | C7658 | 1
10k | RN1,RN2 | RN-9 | C8692 | 2
2k4 | RN3,RN5 | RN-9 | C9107 | 2
IEEE488FLATCABLE | P3,P5 | FLAT24 | C9137 | 2
C64KEYB | P2 | C64KEYB |  | 1
2T2222 | T6 | TO92 |  | 1
M09-182 | X7 | DSUB-9_Pins_Horizontal_P2.77x2.84mm_EdgePinOffset9.90mm_Housed_MountingHolesOffset11.32mm |  | 1
dual 10k linear | RV1 | RK12L12_horizontal |  | 1
Conn_01x07 | J13 | PinHeader_1x07_P2.54mm_Vertical |  | 1
LED3MM | LED1 | LED3MM |  | 1
22000 | C81 | C025-025X050 |  | 1
M09-182 | X8 | DSUB-9_Pins_Horizontal_P2.77x2.84mm_EdgePinOffset9.90mm_Housed_MountingHolesOffset11.32mm |  | 1
Conn_01x01_Pin | J4 | PinHeader_1x01_P2.54mm_Vertical |  | 1
1,8432MHz | QG3 | SG51 |  | 1
Conn_01x01_Pin | J5 | PinHeader_1x01_P2.54mm_Vertical |  | 1
PORT_CASSETTE_EDGE | CN2 | MA156_6-2_KEYED |  | 1
22000 | C79 | C025-025X050 |  | 1
BC557 | Q1 | TO92 |  | 1
2200 | C162 | C025-025X050 |  | 1
M09HPS | X3 | M09HP |  | 1
2200 | C163 | C025-025X050 |  | 1
7.5V | D13 | C1702-15 |  | 1
Conn_01x09 | J11 | PinHeader_1x09_P2.54mm_Vertical |  | 1
0.22 | R49 | 0204_7 |  | 1
Conn_01x09 | J12 | PinHeader_1x09_P2.54mm_Vertical |  | 1
PORT_USER_PET_EDGE | CN5 | MA156_12-2_USER |  | 1
1503_09 | X4 | 1503_09 |  | 1
USB-A-H | USB1 | USB-A-H |  | 1
Conn_01x01_Pin | J1 | PinHeader_1x01_P2.54mm_Vertical |  | 1
D-SUB15-HDR15RA | X2 | DSUB-15-HD_Socket_Horizontal_P2.29x2.54mm_EdgePinOffset8.35mm_Housed_MountingHolesOffset10.89mm |  | 1
2200 | C161 | C025-025X050 |  | 1
0.01, 50V | C125 | C025-024X044 |  | 1
PORT_IEEE_EDGE | CN3 | MA156_12-2_IEEE |  | 1
2T2222 | T7 | TO92 |  | 1
BC547 | T10 | TO92 |  | 1
~ | SW1 | SW_E-Switch-400-combined2 |  | 1
1500p | C114 | C025-024X044 |  | 1
22000 | C78 | C025-025X050 |  | 1
22000 | C80 | C025-025X050 |  | 1
Conn_01x01_Pin | J3 | PinHeader_1x01_P2.54mm_Vertical |  | 1
Conn_01x09 | J10 | PinHeader_1x09_P2.54mm_Vertical |  | 1
0.47 | C126 | C025-025X050 |  | 1
200uH | L4 | TJ4-U2 |  | 1
4700u | C168 | CP_Radial_D16.0mm_P7.50mm |  | 1
1uH | L2 | 0204_7@1 |  | 1
2200 | C164 | C025-025X050 |  | 1
Conn_01x01_Pin | J9 | PinHeader_1x01_P2.54mm_Vertical |  | 1
PIEZOBEEPERPIEZO | BEEP1 | PIEZOBEEPER |  | 1
~ | P10 | Pmod-SDCard |  | 1
CSABUSSOCK180 | P1 | CSABUSSOCK180 |  | 1
Extended_PET_keyboard_connector | J14 | PET_Extended_Keyboard_Connector |  | 1
JP7 | UX26 | JP7 |  | 1
SD-CARD-GRAVI | UX12 | GRAVITECH-SDCARD |  | 1
ETHOLIENC | UX9 | ETHOLIENC |  | 1
DINIEC | UX28 | DIN6PIEC |  | 1

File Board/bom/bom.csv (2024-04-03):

Designator | Footprint | Quantity | Value | LCSC Part #
BEEP1 | PIEZOBEEPER | 1 | PIEZOBEEPERPIEZO
C1, C120, C121, C123, C14, C4, C49, C54, C55, C56, C57 | C0603 | 11 | 1u
C10, C20, C28, C3, C36, C37, C50, C51, C52, C53, C59, C60, C62, C74, C75, C76, C77 | C025-025X050 | 17 | 100n
C100, C101, C102, C103, C104, C105, C106, C107, C108, C109, C11, C110, C111, C112, C113, C12, C13, C15, C16, C17, C18, C19, C2, C21, C22, C23, C24, C25, C26, C27, C31, C32, C33, C34, C35, C41, C42, C43, C44, C45, C46, C47, C48, C58 | C0603 | 44 | 0.1u
C114 | C025-024X044 | 1 | 1500p
C115, C116, C117, C118, C95, C96 | E2-5 | 6 | 1u
C119, C122, C82, C83 | E2-5 | 4 | 10u
C124, C131, C132, C133, C134, C135, C137, C139, C141, C73, C84, C92, C93, C94 | C025-024X044 | 14 | 100n
C125 | C025-024X044 | 1 | 0.01, 50V
C126 | C025-025X050 | 1 | 0.47
C127, C128, C63, C7, C8, C85 | C0603 | 6 | 100n
C130 | E2-4 | 1 | 10u
C140, C72 | E2,5-7 | 2 | 47u
C148, C149 | C025-024X044 | 2 | 0.01u
C150 | C050-025X075 | 1 | 0.1u
C151, C6, C61 | E2,5-6 | 3 | 47u
C29, C30, C39, C40 | C0603 | 4 | 18p
C38 | E2,5-6 | 1 | 22u
C5, C64, C65, C66, C67, C68, C69, C70, C71 | C0805 | 9 | 22u
C78, C79, C80, C81 | C025-025X050 | 4 | 22000
C86, C87, C90, C91 | E2,5-6 | 4 | 1u
C88, C89 | E2,5-6 | 2 | 4u7
C9 | C0603 | 1 | 1.0u Cer
C97, C98 | E2,5-7 | 2 | 100u
C99 | E2,5-7 | 1 | 330u
CN2 | MA156_6-2_KEYED | 1 | PORT_CASSETTE_EDGE
CN3 | MA156_12-2_IEEE | 1 | PORT_IEEE_EDGE
CN5 | MA156_12-2_USER | 1 | PORT_USER_PET_EDGE
D1, D14, D19, D2, D20, D21, D22, D23, D24, D25, D26, D3, D4, D7, D9 | DO35-7 | 15 | 1N4148DO35-7
D10, D5, D6, D8 | D-5 | 4 | 1N4148
D11 | DO201-15 | 1 | 1N5400
D13 | C1702-15 | 1 | 7.5V
D18, D27, D28, D29, D30 | DO35-10 | 5 | 1N4148DO35-10
DS1818 | TO92 | 1 | DS1813
IC1, IC10 | SOP32 | 2 | RAMSOCK32TO512KSOP
IC11, IC28, IC35, IC9 | DIL16 | 4 | 74138N
IC12 | DIL16 | 1 | 74145N
IC13, IC19 | SO20W@1 | 2 | 74244DW
IC14 | SO14 | 1 | 7414D
IC15, IC36 | DIL40 | 2 | VIA
IC16 | SO24L | 1 | 74LVC8T245SO24
IC17, IC20 | DIL40 | 2 | PIA
IC18 | SO14 | 1 | 7406D
IC2, IC4, IC5 | SO20W@1 | 3 | 74245DW
IC21 | DIL14 | 1 | 7417N
IC22 | DIL14 | 1 | 7400N
IC23 | DIL14 | 1 | 7486N
IC25 | DIL16 | 1 | 74139N
IC26 | DIL14 | 1 | LM3900N
IC27, IC40 | DIL14 | 2 | 7474N
IC29 | DIL14 | 1 | 556N
IC3 | SO14@1 | 1 | 74125D
IC31, IC32 | DIL16 | 2 | MAX232
IC33 | PLCC44 | 1 | UARTPLCC
IC34 | DIL14 | 1 | 7406N
IC48 | DIL14 | 1 | 7414N
IC49 | DIL20 | 1 | 74241N
IC7 | SO16 | 1 | 74138D
IC8 | TQFP32-5MM | 1 | MAX3421E
J1, J3, J4, J5 | PinHeader_1x01_P2.54mm_Vertical | 4 | Conn_01x01_Pin
J2 | DCJ0202 | 1 | DCJ0202
JP1, JP11, JP12, JP15, JP17, JP2, JP3, JP4, JP6 | JP1 | 9 | JP1E
JP10 | JP3Q | 1 | JP3Q
JP13, JP14, JP16, JP18, JP20, JP21, JP22, JP23, JP24, JP25, JP26, JP27, JP28, JP29, JP31, JP5, JP8 | JP2 | 17 | JP2E
JP30 | JP6Q | 1 | JP6Q
JP7 | JP4 | 1 | JP4E
JS1 | RENJS6 | 1 | RENOSCXLH
L2 | 0204_7@1 | 1 | 1uH
L4 | TJ4-U2 | 1 | 170-200uH
LED1 | LED3MM | 1 | LED3MM
P1 | CSABUSSOCK180 | 1 | CSABUSSOCK180
P2 | C64KEYB | 1 | C64KEYB
P3 | FLAT24 | 1 | IEEE488FLATCABLE
P5 | FLAT24 | 1 | PETUSERPORT
P6, P7 | JP6 | 2 | CBMTAPE
P8 | C64KEYB | 1 | PETKEYBD
Q1 | TO92 | 1 | BC557
Q2 | TC26H | 1 | 32kHz
Q3 | HC49_S | 1 | 12MHz
Q4 | MICRO3 | 1 | IRLML5203
QG1 | SG51 | 1 | 50MHz
QG2 | SG51 | 1 | 16MHz
QG3 | SG51 | 1 | 1,8432MHz
R1, R2, R32, R4 | 0204_7 | 4 | 33
R10, R11, R24, R30, R9 | 0207_2V | 5 | 10k
R101, R34, R35, R86, R87 | 0207_10 | 5 | 4k7
R103, R74, R75 | 0207_10 | 3 | 10k
R12 | 0207_2V | 1 | 1k5
R13, R14, R15 | 0204V | 3 | 470
R16, R27, R6 | 0204_5 | 3 | 10k
R17, R26 | 0204_7 | 2 | 10k
R18, R19, R20 | 0204V | 3 | 1k
R22 | 0207_2V | 1 | 390
R25 | 0207_2V | 1 | 4k7
R28, R31 | 0204V | 2 | 100
R29 | 0207_2V | 1 | 330
R33 | 0207_10 | 1 | 10
R48 | 0207_2V | 1 | 100k
R49 | 0204_7 | 1 | 0.22
R5 | 0207_2V | 1 | 1k
R50 | 0204_7 | 1 | 180
R52, R54, R56, R58, R60, R62, R64, R66 | 0204_7 | 8 | 100K
R53, R57, R61, R65 | 0204_7 | 4 | 10M
R55, R59, R63, R67 | 0204_7 | 4 | 470
R68, R69 | 0204_7 | 2 | 47k
R7, R8 | 0204V | 2 | 68
R73 | 0207_10 | 1 | 1k
R76 | 0207_7 | 1 | 15k
R77, R79, R80 | 0207_7 | 3 | 100k
R78 | 0207_7 | 1 | 10k
R81 | 0207_7 | 1 | 470
RG0 | 0204_7 | 1 | 1k1
RN1, RN2 | RN-9 | 2 | 10k
RN3, RN5 | RN-9 | 2 | 5k1
RN4, RN6 | RN-9 | 2 | 2k4
RN8 | RN-8 | 1 | 10k
RS0 | 0204_7 | 1 | 6k8
S1, S2 | B3F-31XX | 2 | 31-XX
SJ1 | SJ_2 | 1 | SJ2W
SN1 | SOIC8 | 1 | MCP48X2
SW1 | SW_E-Switch-400AWMDPxR1M1x | 1 | ~
T10 | TO92 | 1 | BC547
T6, T7 | TO92 | 2 | 2T2222
T8 | TO220 | 1 | TIP31
U$1 | PLCC44 | 1 | W65C816SPLCC
U$10, U$11, U$14, U$15, U$5, U$6, U$8 | SOD323 | 7 | ESDBIDIR
U$12 | GRAVITECH-SDCARD | 1 | SD-CARD-GRAVI
U$13 | MSOP10 | 1 | MCP79510
U$16 | PSOP-8-FIXED | 1 | AP2132BB
U$18, U$4 | DIL08 | 2 | SPIFLASH
U$19 | TQFP144 | 1 | XC6SLX9-TQG144
U$20, U$21 | DIL20 | 2 | 74LS641
U$22, U$23 | DIL28 | 2 | SID
U$24 | DIL08 | 1 | MC34063A
U$25 | FABC48R2 | 1 | CSASHORTBUSFA
U$26 | JP7 | 1 | JP7
U$27 | JP5 | 1 | JP5
U$28 | DIN6PIEC | 1 | DINIEC
U$3 | SOT223 | 1 | LDI1117
U$7 | FLAT10BOX | 1 | XILINXPROG
U$9 | ETHOLIENC | 1 | ETHOLIENC
U1 | SOT-23-5 | 1 | 74LVC1G04
USB1 | USB-A-H | 1 | USB-A-H
X1 | FPS009-3000 | 1 | FPS009-300
X2 | HDR15RA | 1 | D-SUB15-HDR15RA
X3 | M09HP | 1 | M09HPS
X4 | 1503_09 | 1 | 1503_09
X7, X8 | 182-009-MALE | 2 | M09-182

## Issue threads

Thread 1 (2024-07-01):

Simplify the BOM

fachat, 2024-07-01:
In the BOM there are multiple parts that are actually the same value, or could be unified. Some have different parts in the Mouser BOM, in other places it's only a difference in footprint

* C86, C87, C90, C91 could be unified with C95, C96, ... (1u electrolyte cap) - diff. footprints, diff. parts
* C125 <-> C148, C149: diff footprints
* C130 <-> C82, C83, C119, C122: diff. footprints
* C138, ... <-> C74, ... : diff. footprints
* R6, R16 <-> R10, R11, ... <-> R78 <-> R74, R75 : diff footprints
* R48 <-> R62, .. <-> R77, ... <-> R52, ... : diff footprints
* R73 <-> R5 <-> R18, ... : diff footprints
* ...

fachat, 2024-07-07:
- C38 -> 47u
- C32, C104 -> 1u
- C14, C56, C120 -> 0.1u
-

fachat, 2024-07-08:
- R33, R1, R2 -> diff. footprints

fachat, 2024-07-09:
100n caps through hole:
- C3, C10, ... <-> C73, C84, .. diff. footprints

fachat, 2024-07-10:
- R77, R79, R80 <-> R52, R54, ... - diff footprints

fachat, 2024-07-10:
- R3, R21, ... <-> R13, R14, R15 <-> R81: diff. footprints

fachat, 2025-08-30:
Ongoing. Now working on full assembly by PCB house.

Closed 2025-08-30.

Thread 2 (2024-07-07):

Power switch wrong direction

fachat, 2024-07-07:
1.1A

If using the small, up/down power switch, the down position is on, and up is off.
It should be the other way round.

Closed 2024-10-14.

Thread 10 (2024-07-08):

The BOM is one 14-pin socket short

fachat, 2024-07-08:
R1.1A

fachat, 2024-07-08:
No it isn't - I overlooked one socket in the tube they came in

Closed 2024-07-08.

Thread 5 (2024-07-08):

Set IC values to correct family

fachat, 2024-07-08:
In 1.1A: Some ICs have old/wrong family type values, like 74125D instead of 74LVC125D, and appear as such in the bom. These values should be updated

- IC3 -> 74LVC125D
- IC7 -> 74LVC138D
- IC14 -> 74LVC14 - this is actually wrong in the BOM, where a 74LV14 is used (but seems to work nonetheless)
- IC18 -> 74LVC06

fachat, 2024-10-14:
in branch 1.2

Closed 2024-10-14.

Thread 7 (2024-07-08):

Does R22 need to be 390Ohm?

fachat, 2024-07-08:
R1.1A - LED current limiting resistor.

fachat, 2024-10-13:
For the chosen (as it seem not low power) LED it should actually be 150 Ohm...:
5V VCC minus 2V Vf is 3V over the resistor, for 20mA current that gives 150 Ohm.

I could probably use a low power LED if it is same price or less. Should also be considered for the shift lock LED.

Closed 2024-10-13.

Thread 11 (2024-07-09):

JP8 silkscren

fachat, 2024-07-09:
JP8 belongs into the "Select" section, and needs silkscreen note that
it is left=$e8xx and right = $efxx I/O

(R1.1A)

fachat, 2024-10-13:
replaced with solder jumper anyway. Will only be changed if/when someone looks at schematics, so no silkscreen needed.

Closed 2024-10-13.

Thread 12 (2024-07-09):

Pulldowns needed on DUART's INTA/B

fachat, 2024-07-09:
The 16C752 datasheet says - if you read it carefully enough - that the INTA and INTB outputs are "high impedance after reset". That wouldn't have been a problem if they had been wire-ORd with the /IRQ, but in original intel strangeness, they are active high, so I have open collector output inverters on those signals. And they read high impedance as high, thus pulling /IRQ low, resulting in an infinite interrupt loop. Argh.

fachat, 2024-10-13:
This should/could be handled in software, but ... anyway, pulldowns are in r1.2

Closed 2024-10-13.

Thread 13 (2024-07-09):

Old/New SD-Card adapter have silkscreen wrong

fachat, 2024-07-09:
The orientation for the PCB for the new adapter that is drawn on the silkscreen is on the front side - but it should be on the back side.

fachat, 2024-07-09:
Argh. also for the original adapter. The PCB has to point to the back, but it is drawn pointing to the front.

fachat, 2024-07-09:
Thus the original adapter conflicts with the new one, as the old adapter PCB reaches over the new adapter's socket.

But I think that is ok. The old one is not available anymore, so the pins are just connectors for potential cable connections to other types of SD-Card adapters. Right?

fachat, 2024-10-13:
silkscreen fixed on branch r1.2

Closed 2024-10-13.

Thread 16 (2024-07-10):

BOM has one 9-pin D-Sub too many?

fachat, 2024-07-10:
3 D-Sub male sockets for joysticks instead of two?

fachat, 2024-10-13:
seems to be correct though.

Closed 2024-10-13.

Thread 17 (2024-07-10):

Caps

fachat, 2024-07-10:
- BOM has 10 1u MLCC - probably duplicates to 1u Electrolyte caps
- Board seems to work without all the caps underneath the FPGA...? - keep them in place, or move them to the top (maybe in reduced numbers)
- 1u SMD caps are completely left out and still works.

fachat, 2024-12-01:
r1.2 has the caps moved from the underside to the top, so they can be assembled by an assembly house.

Audio electrolyte caps have been replaced with MLCC in the BOM.

1u SMD caps are still there. If manufactured, they only add fractional cost, and (hopefully) help.

Closed 2024-12-01.

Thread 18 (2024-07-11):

Comment on schematics, Userport page

fachat, 2024-07-11:
... says to use "female connectors" - but the sockets on the Computer are male, the connectors on the joysticks are female.
The BOM actually has the correct parts.

fachat, 2024-10-13:
fixed in branch r1.2

Closed 2024-10-13.

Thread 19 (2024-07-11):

Dual joysticks Fire port 1 and 2 do not work

fachat, 2024-07-11:

fachat, 2024-07-11:
.... which of course is a stupid bug: the diodes to let "fire" register as simultaneous "up" and "down" are the wrong way around!

fachat, 2024-10-13:
Is in branch r1.2

Closed 2024-10-13.

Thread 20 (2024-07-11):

Remove the 50 MHz oscillator option

fachat, 2024-07-11:
... and maybe improve the footprint for the 70MHz oscillator package to one that's a bit easier to solder manually.

fachat, 2024-10-13:
Removed 50MHz DIL socket.
Unfortunately it seems no larger 70MHz oscillator package seems available.

is in branch r1.2

Closed 2024-10-13.

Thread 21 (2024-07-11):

Is JP31 really needed?

fachat, 2024-07-11:
As JP31 is only there for the situation when WDC has fixed the VIA shift register "bug". And that may be years to come.
So, does it make sense to include it, esp. as the schematics should work in "buggy VIA" mode even with a fixed one...?

For details see here
https://www.youtube.com/watch?v=6cwVQahVCdc
and the followup video with WDC's response.

fachat, 2024-10-13:
replaced with solder jumper in branch r1.2

Closed 2024-10-13.

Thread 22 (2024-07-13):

R3 is wrong value

fachat, 2024-07-13:
The schematics says 470 Ohm, but it should be 3k3.

fachat, 2024-07-13:
To make beeper less "aggressive" compared to the other mixer inputs, R3 should be 4k7

fachat, 2024-10-13:
already included in branch r1.2

Closed 2024-10-13.

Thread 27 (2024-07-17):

UART port B DSR (and maybe CD) should be low instead of high

fachat, 2024-07-17:
... as otherwise the driver would think the line is offline, and not send anything....

fachat, 2024-10-10:
added in branch 1.2a

Closed 2024-10-10.

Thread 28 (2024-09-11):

bom link on title readme is broken (eom)

fachat, 2024-09-11:

fachat, 2024-10-13:
In branch r1.2

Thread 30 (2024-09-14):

2nd SID is not selected

fachat, 2024-09-14:
The 2nd SID is actually not selected at all.

/LOCALIO has BA7=0 in it, so the upper half of the $e8xx block is never selected.

Resolution: move BA7 to IC9 pin 4 instead?

fachat, 2024-09-14:
yes. this works. Verified by patching 1.0A and 1.1A prototypes

fachat, 2024-10-10:
added in branch 1.2a

Closed 2024-10-10.

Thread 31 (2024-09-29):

FPGASID conflicts with other ICs

fachat, 2024-09-29:
Trying to plug in the FPGA SID is prevented by spatial conflict with other ICs, namely one of the I/O chips, and the select chips, if they are socketed.

Initial mititation: trying a socket underneath the FPGASID.

But: need to change layout

fachat, 2024-10-19:
moved in branch 1.2

Closed 2024-10-19.

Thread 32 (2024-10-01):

SPI-10 and UEXT as well as TTLserial connectors are underneath the keyboard support

fachat, 2024-10-01:
In the 3D printed case, the SPI-10, UEXT, and TTL serial connectors are all located under the keyboard support.
They should be moved more to the back of the board to be more easily accessible

fachat, 2024-10-19:
moved in branch 1.2

Closed 2024-10-19.

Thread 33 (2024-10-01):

Shift-LOCK LED needed

fachat, 2024-10-01:
As currently there is no way to see if shift lock is active or not, an LED should be added to show its state.

fachat, 2024-10-07:
Use IC27B pin 8 as input into IC3D pin 13, to pull output low when SHIFT LOCK is active

fachat, 2024-10-10:
Added in branch 1.2a

Closed 2024-10-10.

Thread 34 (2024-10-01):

Use 1N4448 instead of 1N4148 where appropriate

fachat, 2024-10-01:
The 1N4448 has a guaranteed forward voltage of 0.73V for currents below 5mA.
The 1N4148 has a guaranteed forward voltage of 1V for currents under 10mA.

This means if the current is <5mA, only 1N4448 guarantees to stay under the .8V TTL Vil upper limit

fachat, 2024-10-13:
Changed:
- userport diodes for dual joystick mode
- IRQ diodes for both VIAs

in branch r1.2

Closed 2024-10-13.

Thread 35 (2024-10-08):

Second 3.3V generation for the bus

fachat, 2024-10-08:
Currently the bus uses the same 3.3V that is used for the main FPGA, CPU, RAM etc.

At least the bus, if not even the net and SDcard ports should have their own 3.3V generation.

fachat, 2024-10-08:
Currently the old SDcard connector uses 5V, not 3.3V

- USB MAX3421 max rating is 55mA at 3.3V
- ENC28J60 while transmitting: 180mA at 3.3V
- SDCards Class 10 specifiy up to 100mA at init, 200mA in high speed mode, and 500mA in "other functions" (https://www.farnell.com/datasheets/1683445.pdf)
- ESP32-C3-WROOM-02: up to 345mA peak (https://www.espressif.com/sites/default/files/documentation/esp32-c3-wroom-02_datasheet_en.pdf)
- Spartan6 quiescent mode approx. 8mA, 40mA during fuse. Lots if pins are added. Up to multiple Amps possible. Currently during full speed operation, FPGA stays quite cool actually, so in reality not that much
- IS61C512 (2x) up to 70mA (RAM)

fachat, 2024-10-08:
I think I should have a 2nd 3.3V generator for SDcard, Network (Eth or Wifi/ESP32), and bus (for the ultipet)

fachat, 2024-10-10:
Added in branch 1.2a

Closed 2024-10-10.

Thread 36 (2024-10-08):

One 32G SD Card does not start on powerup

fachat, 2024-10-08:
When sitting in the slot during powerup, the SD won't react anymore.
Taking it out and re-seating it makes it work again.

The type is a "Lexar MicroSDHC I V10 A1 32GB" card.

Other cards seem to work just fine after powerup.

Is this a power supply issue?

fachat, 2025-01-26:
Even with additional large power supply bypass caps, the SD-Card does not start on powerup. It works immediately after inserting still.

Pushing the RESET button when it hangs after powerup does not help either

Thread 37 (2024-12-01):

The expansion port pinout is reversed.

fachat, 2024-12-01:
The connector on the Ulti-PET is a "reversed" connector according to https://en.wikipedia.org/wiki/DIN_41612
Unfortunately I did not account for the inverse numbering, where a1 becomes a32 and vice versa...

This is in all Ulti-PET so far (1.0, 1.1, 1.2)

fachat, 2025-01-26:
footprint corrected in 1.3, layout tbd

fachat, 2025-08-30:
Fixed in R1.3A

Closed 2025-08-30.

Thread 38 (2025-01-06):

r1.2a: SPI clk needs to be more transmission line.

fachat, 2025-01-06:
Small caps on the SPI clk prevented the system from booting.
Even touching SPI_CLK on the SD card connectors did this. So, it didn't start with an SD card adapter in the connector.

Cutting off the SPI-3.3/UEXT trace of the SPI CLK helped. This needs to be remedied.

Or maybe that's this specific prototype? Booting with SD adapter works now, but not with SD card inserted.

fachat, 2025-08-30:
Fixed in R1.3A:
- termination resistors according to FPGA spec
- extra driver for the external SPI (on SPI-10-3.3V and UEXT)

Closed 2025-08-30.

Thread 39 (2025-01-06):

r1.2a: power LED limiting resistor R17 is unconnected

fachat, 2025-01-06:
... and missing its connection to VCC.

fachat, 2025-01-26:
done in 1.3

Closed 2025-08-30.

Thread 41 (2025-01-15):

Wrong potentiometer taper

fachat, 2025-01-15:
The volume potentiometer is using an audio taper. Experience shows the taper should be linear.
Also, the current BOM parts is not recommended for new designs.

Therefore, replace it with https://www.mouser.de/ProductDetail/BI-Technologies-TT-Electronics/P120KGP-F15BR10K
which seems to have a very similar footprint. Also, use a 10k resistor from the input (audio connector) to the audio input instead of the 56k as given in the Known Issues.

fachat, 2025-01-26:
done for 1.3

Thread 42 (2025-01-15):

Not HDMI-ready

fachat, 2025-01-15:
The digital video out connector was meant to be not only for experimenting with composite video timing, but also HDMI timing.

However, to properly support HDMI, the output lines from the FPGA must be pairwise N/P output driver for Low voltage differential, and the signal lines should be impedance matched.

This should be fixed in the next prototype.

fachat, 2025-08-30:
Pinouts in R1.3A have been changed so video output is done via 4 pairs of LVD-capable output pairs in the FPGA (even though it's still VGA for now, an adapter can be used on the digital video out connector to test HDMI output)
(See "HDMItest" board in r1.3 branch)

Closed 2025-08-30.

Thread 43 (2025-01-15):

RS232 extension

fachat, 2025-01-15:
The TTL connectors for the RS232 should include DTR and maybe others.

DTR comes in handy for programming the ESP32 with that reset-circuit on DTR/RTS
as seen here https://electronics.stackexchange.com/questions/473443/esp32-dev-board-dtr-rts resp. https://dl.espressif.com/dl/schematics/ESP32-Core-Board-V2_sch.pdf

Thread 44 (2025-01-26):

Separate 9V gen to reduce audio issues

fachat, 2025-01-26:
9V generation seem to introduce power supply issues that bleed through to the audio section.

Closed 2025-08-30.

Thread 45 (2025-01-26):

pin for connecting 2nd SID chip select

fachat, 2025-01-26:
This is useful for FPGASID which has a chip select entry to enable a 2nd SID.

E.g. plug the FPGASID into SID1 socket, and connect its 2nd select input to the chip select of the SID2 socket.

fachat, 2025-08-30:
Done in 1.3A

Closed 2025-08-30.

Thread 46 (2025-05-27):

r1.2a: Missing Ground Pads for VGA and Joysticks

torstenbuelck, 2025-05-27:
The 9-pin connectors for VGA and the two joysticks lack ground pads on the solder side for soldering the shield pins.

This results in a loss of stability, requiring additional screws.

fachat, 2025-08-30:
Done in R1.3A

Closed 2025-08-30.

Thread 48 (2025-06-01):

r1.2a: Optional resistor on AUDIO_OUT for old SIDs (6581)

tutigit, 2025-06-01:
The SID 6581 requires an additional resistor between pin 27 (AUDIO_OUT) and GND. This resistor should be optionally equippable. Ideally, it can be mounted with a 1RM footprint. For vertical mounting of the resistor itself or a female header for plugging in. Alternatively, it can be permanently mounted with a jumper for activation.

fachat, 2025-08-30:
Implemented as R45 and R46, with jumpers JP9 and JP15 in R1.3A

Closed 2025-08-30.

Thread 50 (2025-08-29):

R1.3A: Holes for poti RV1 are too small

fachat, 2025-08-29:

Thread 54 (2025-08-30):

R1.3A: sound with SID installed is ok, without very bad Userport sound

fachat, 2025-08-30:
A very strange effect - if a (dual) SID is installed, the sound is completely fine - if the SIDs are removed, userport sound is very much distorted
In this case a (dual) ARM2SID

fachat, 2025-08-30:
Observations:
- it seems to be a problem on the digital side, not the analog side. I cut off the beeper signal from R3 and R27, and used a piezo only, still distorted
- does not depend on VIA - swapped them with each other, and with the working 1.2A board, it was only ever in the 1.3A without ARM2SID where the problem happened
- An X-SID in place of the ARM2SID does not help. It's still distorted, no matter if either one or both SID sockets are populated

fachat, 2025-08-30:
Something very weird. The burnin test does not start when the UltiBus is connected, it starts without (with distorted sound).
RAM test is fine. T1 and T2 are off. "BAD 2B44" resp. "BAD 2B45" instead of OK (2AD6)
Burnin starts with FPGASID in SID1 socket, RAM still ok, but T1/T2 now show 5663/5666

fachat, 2025-08-30:
IC40 was inserted the wrong way, which made the bus' Phi2 going to 1V only.... It's actually a wonder that the machine still worked...

Closed 2025-08-30.

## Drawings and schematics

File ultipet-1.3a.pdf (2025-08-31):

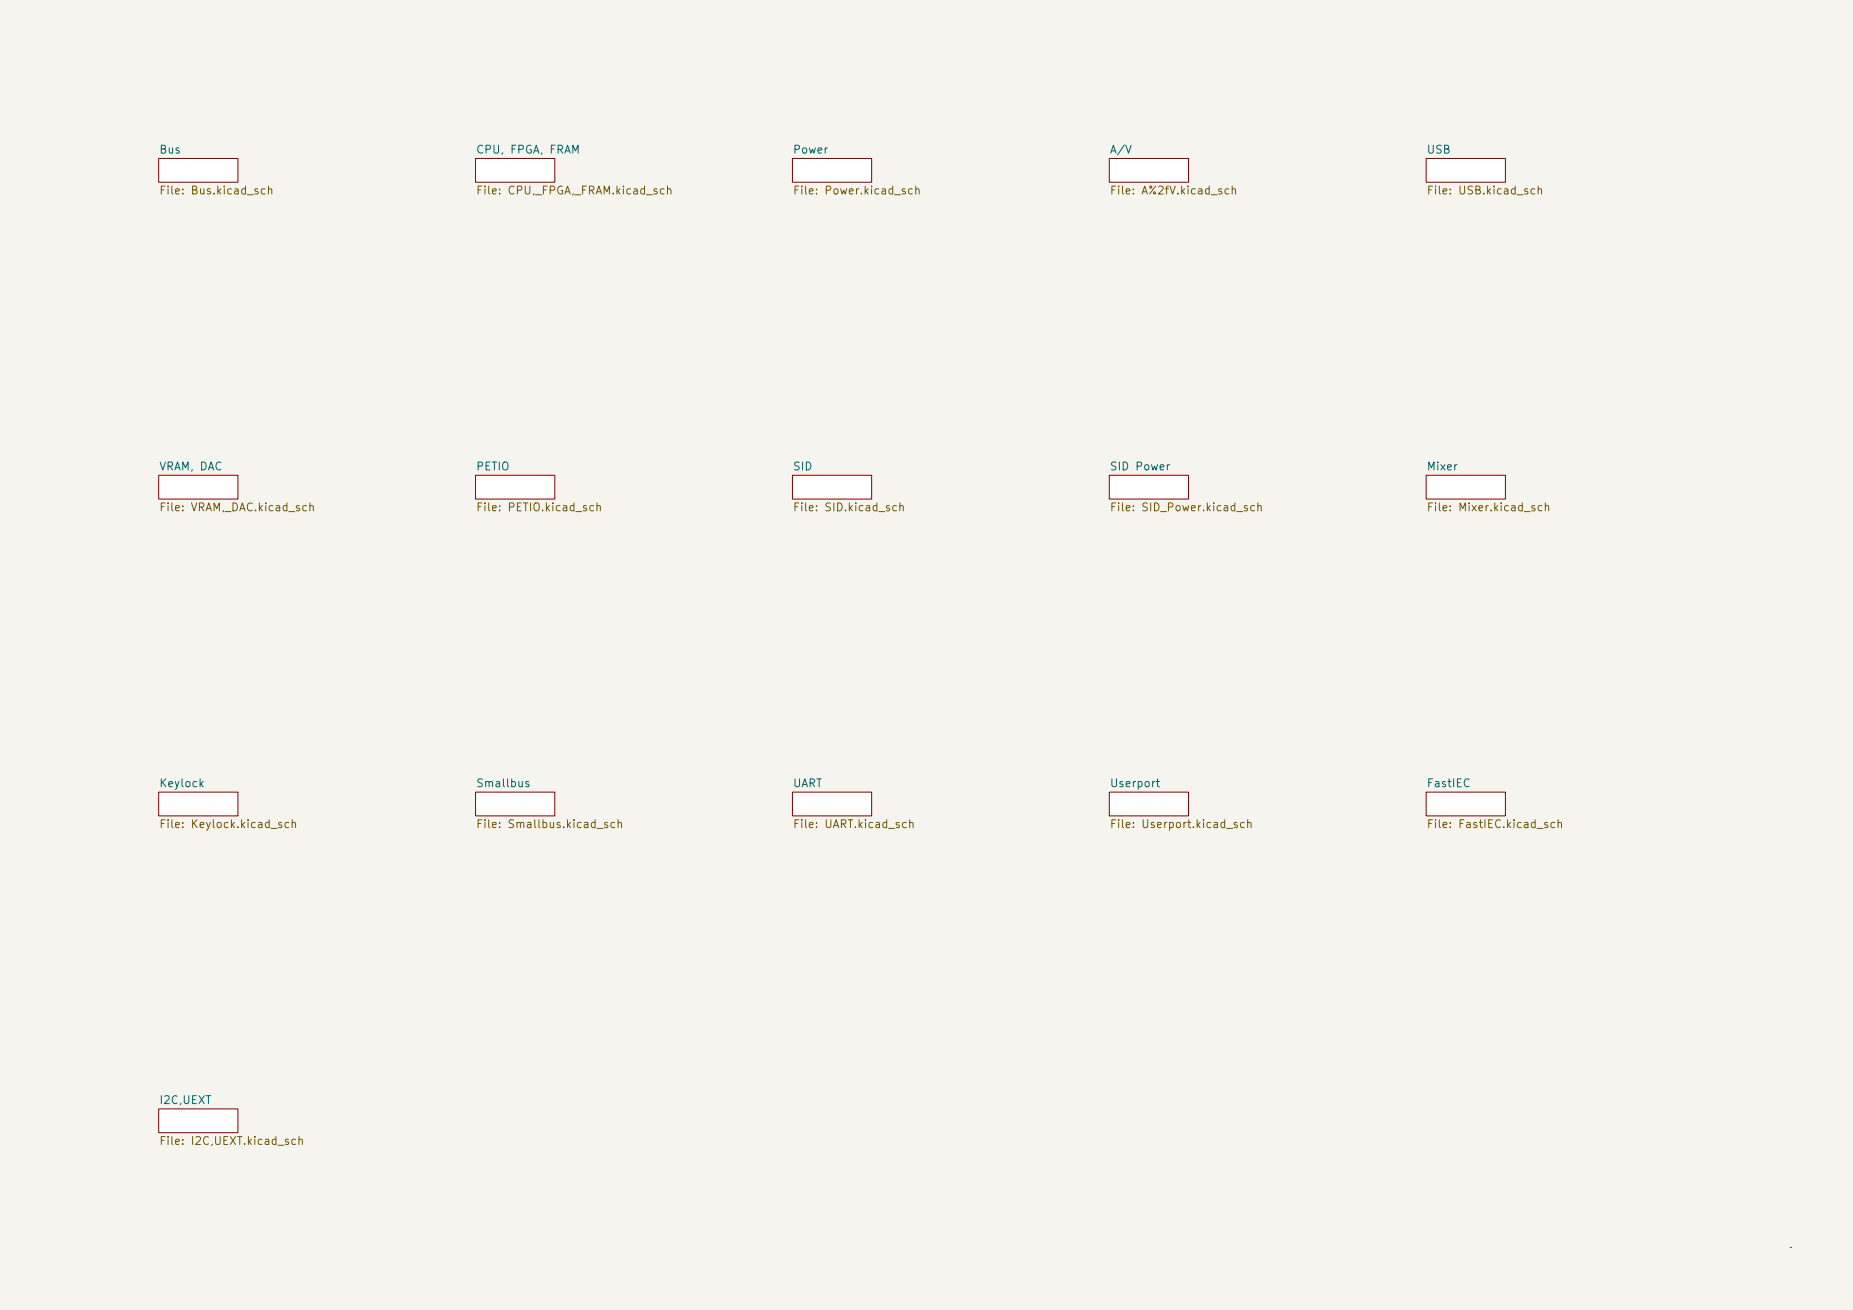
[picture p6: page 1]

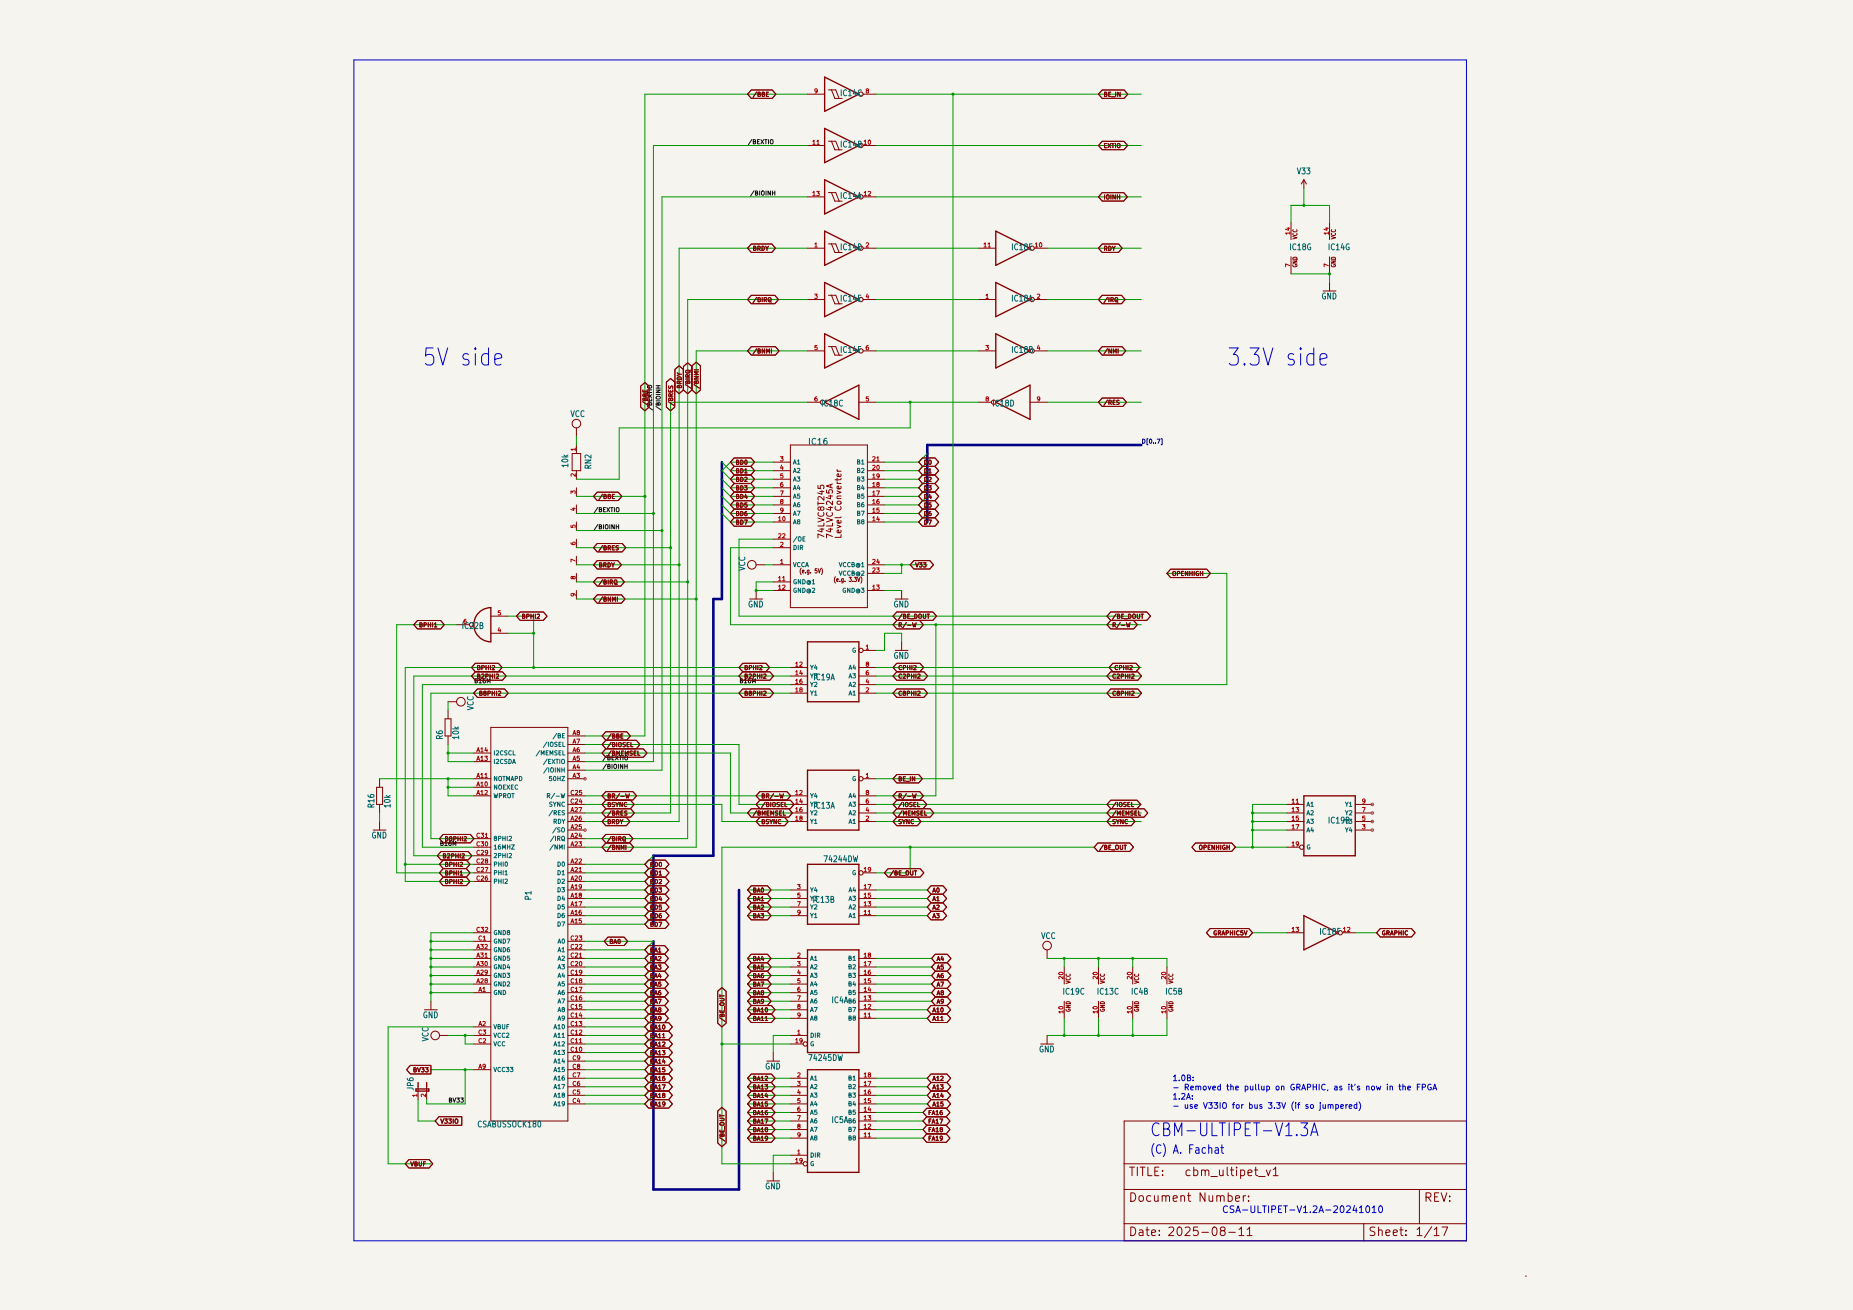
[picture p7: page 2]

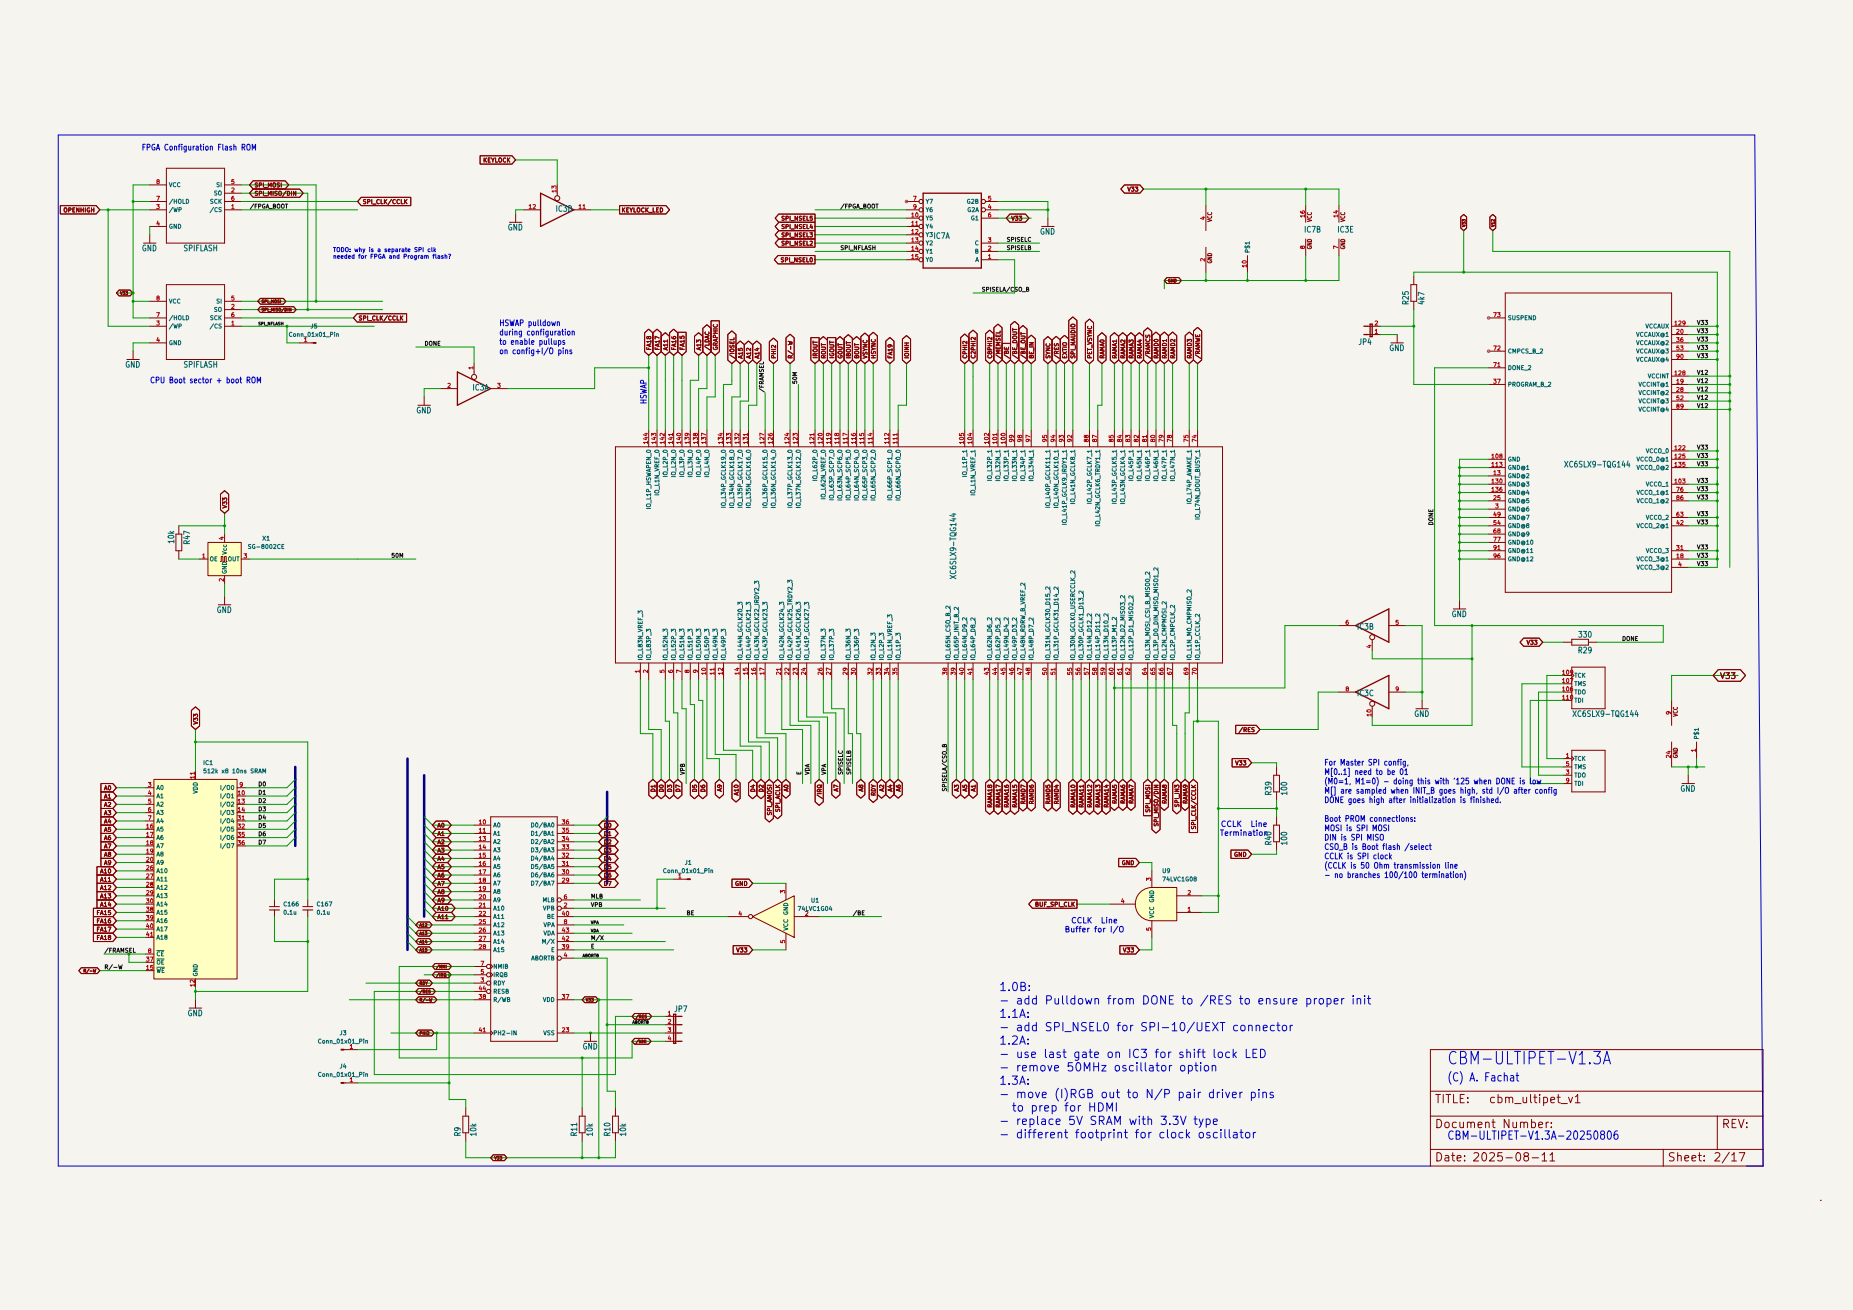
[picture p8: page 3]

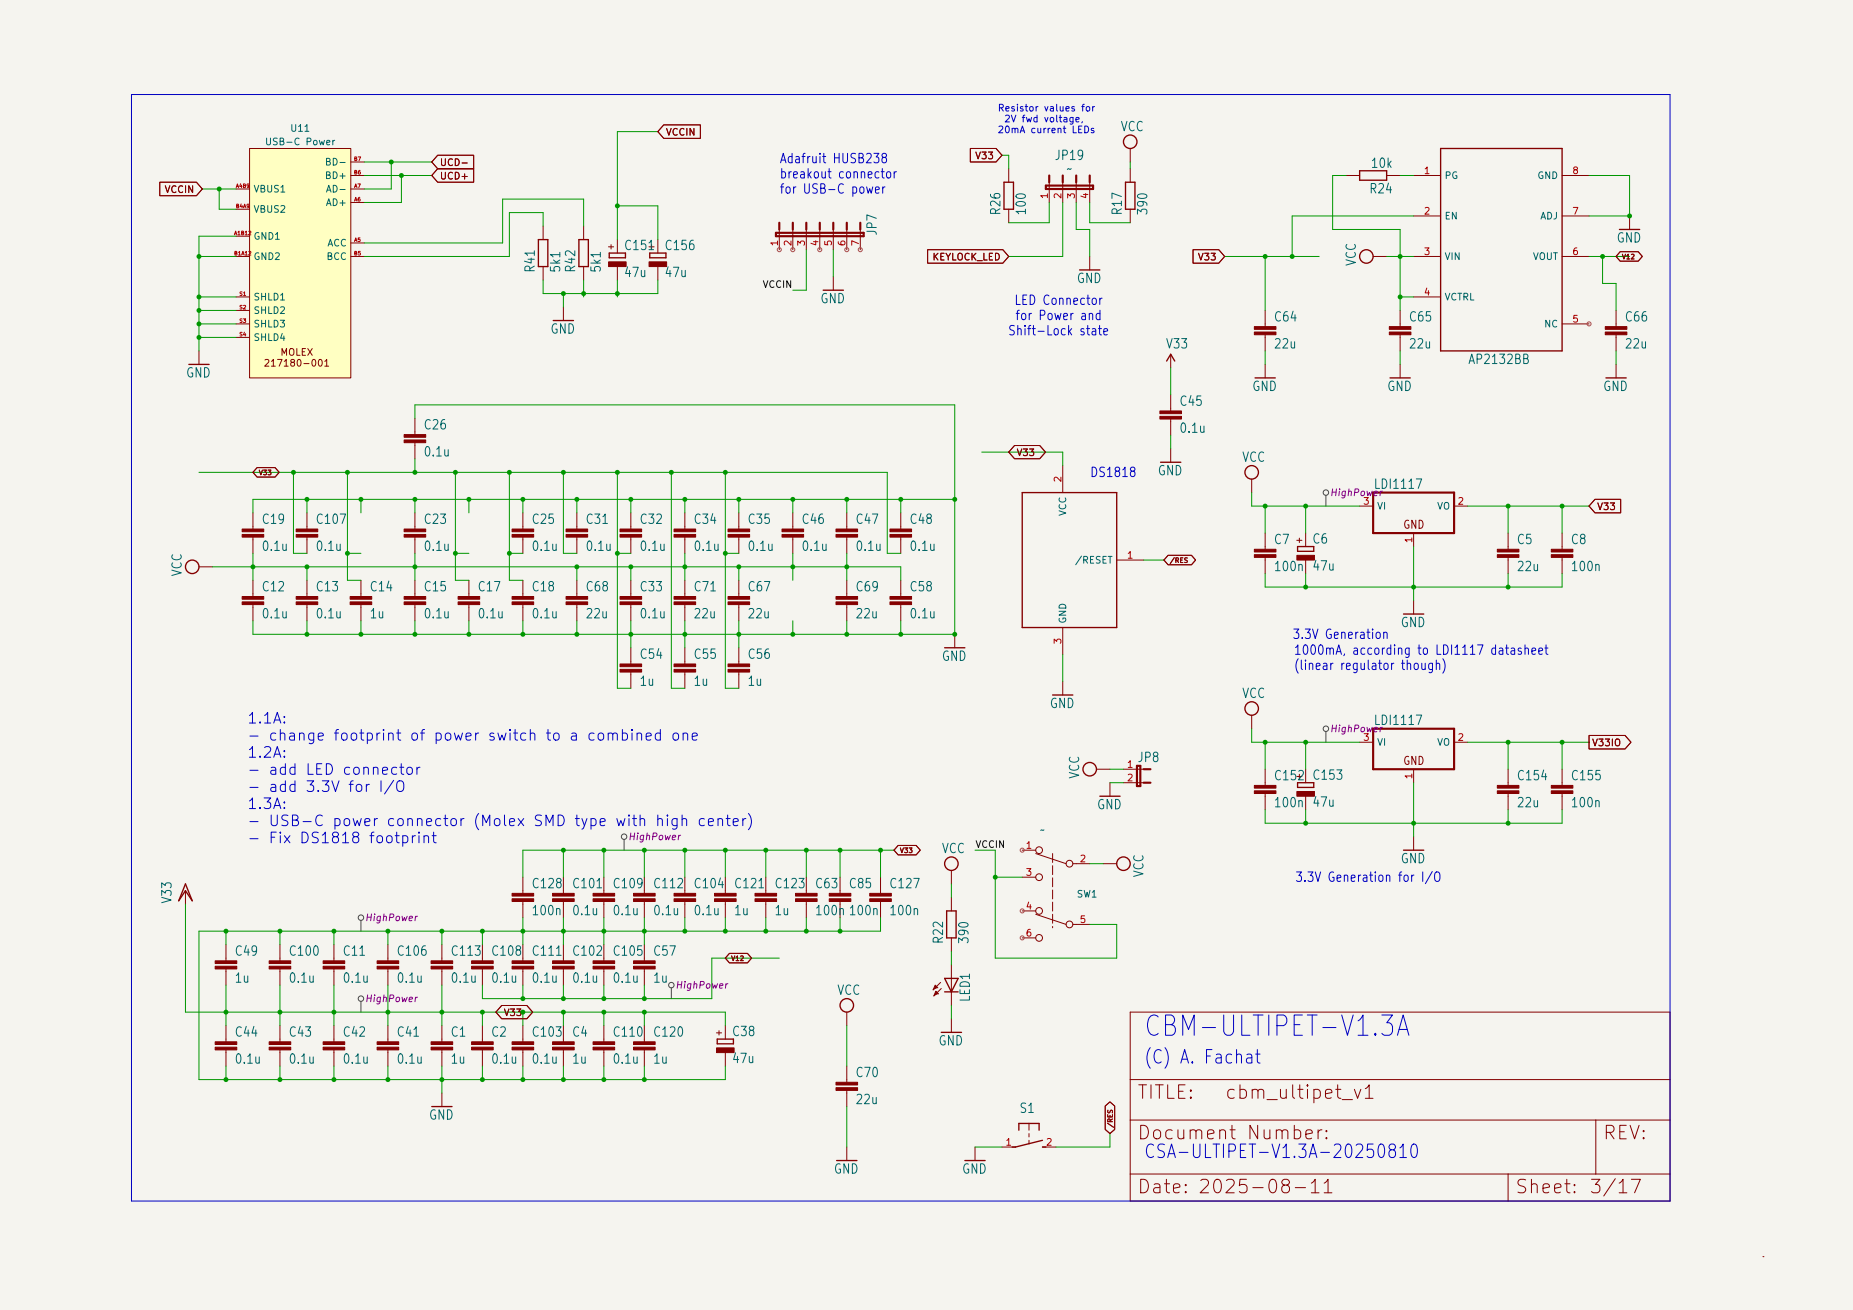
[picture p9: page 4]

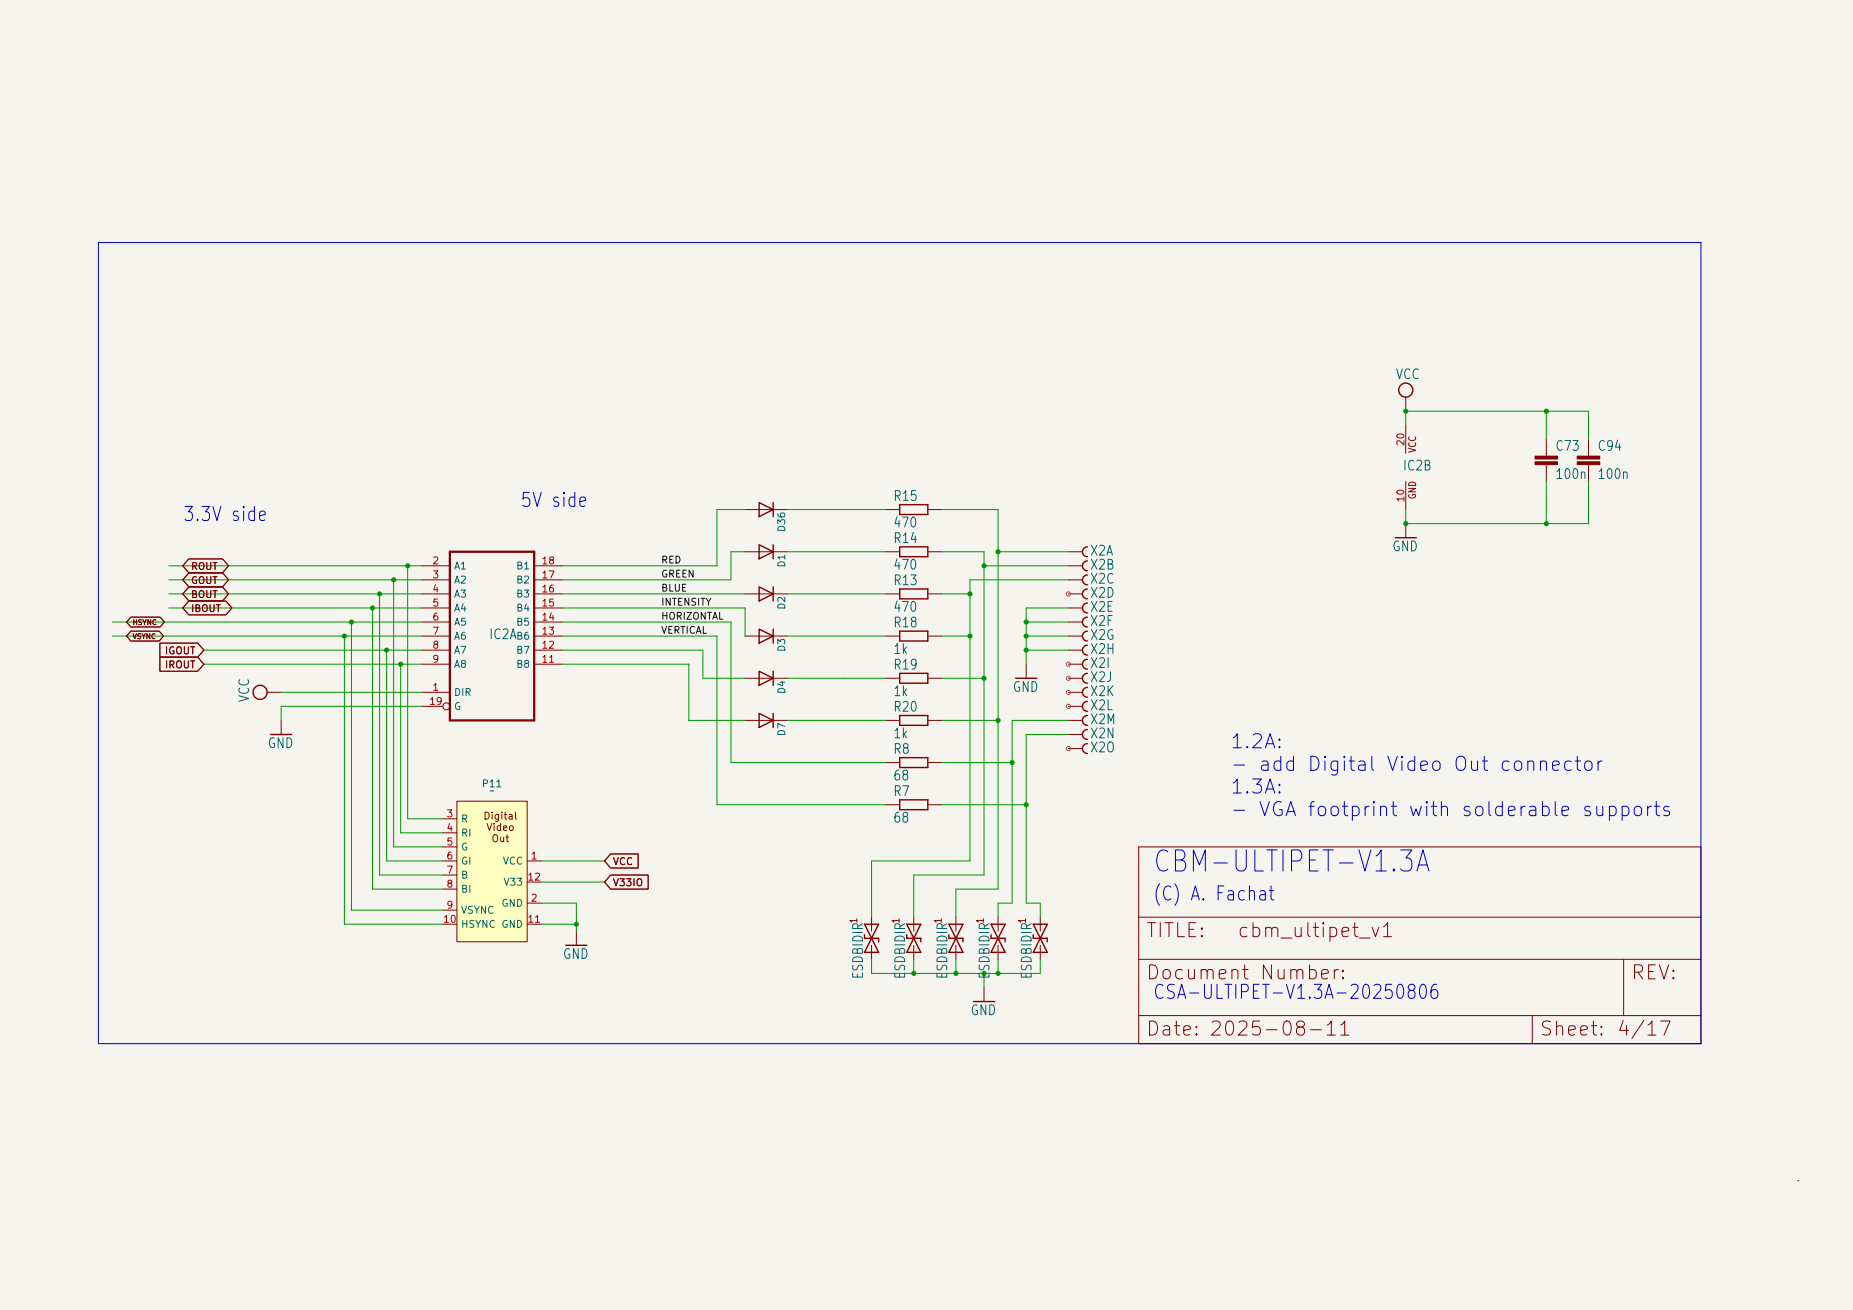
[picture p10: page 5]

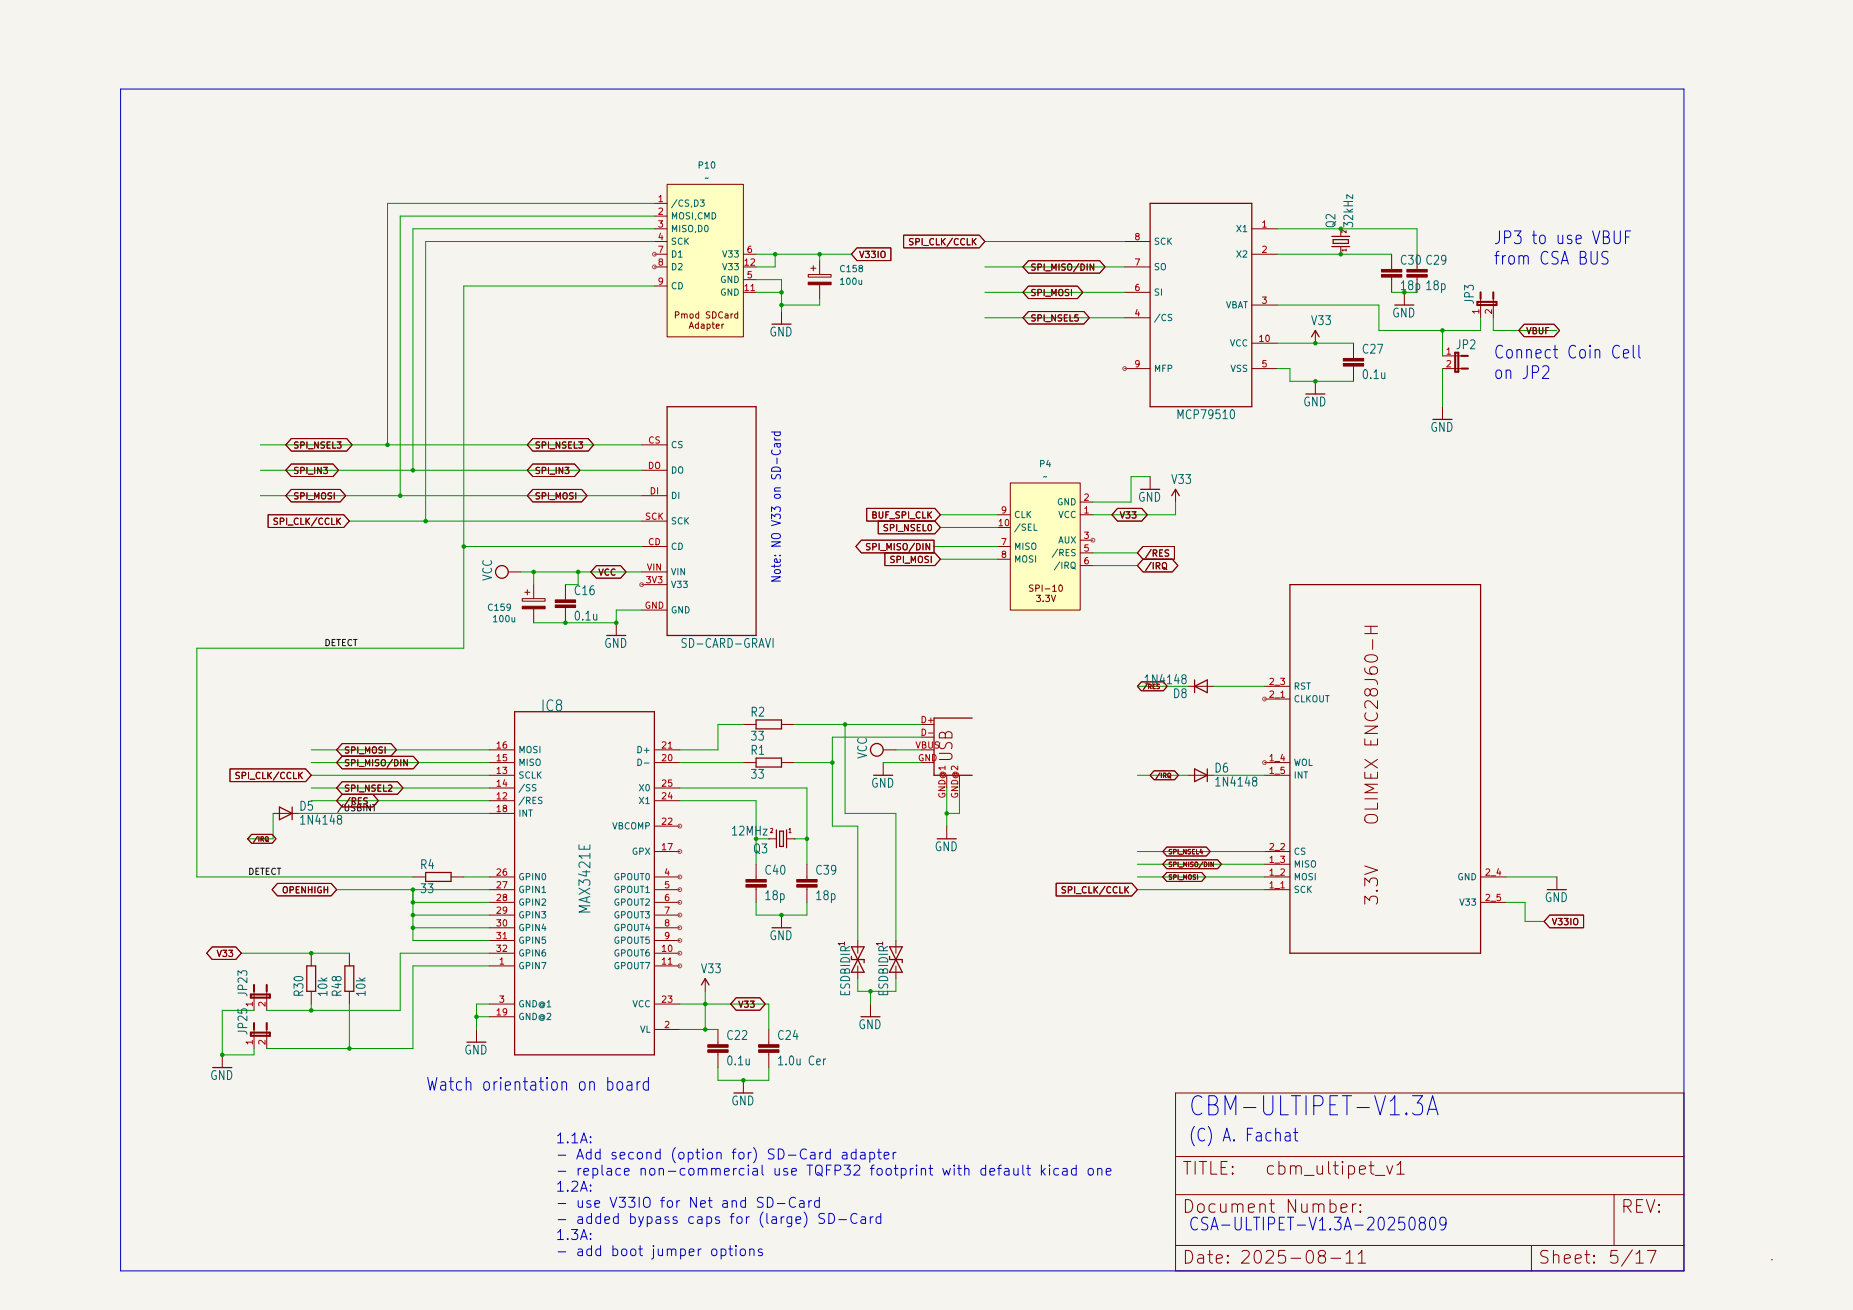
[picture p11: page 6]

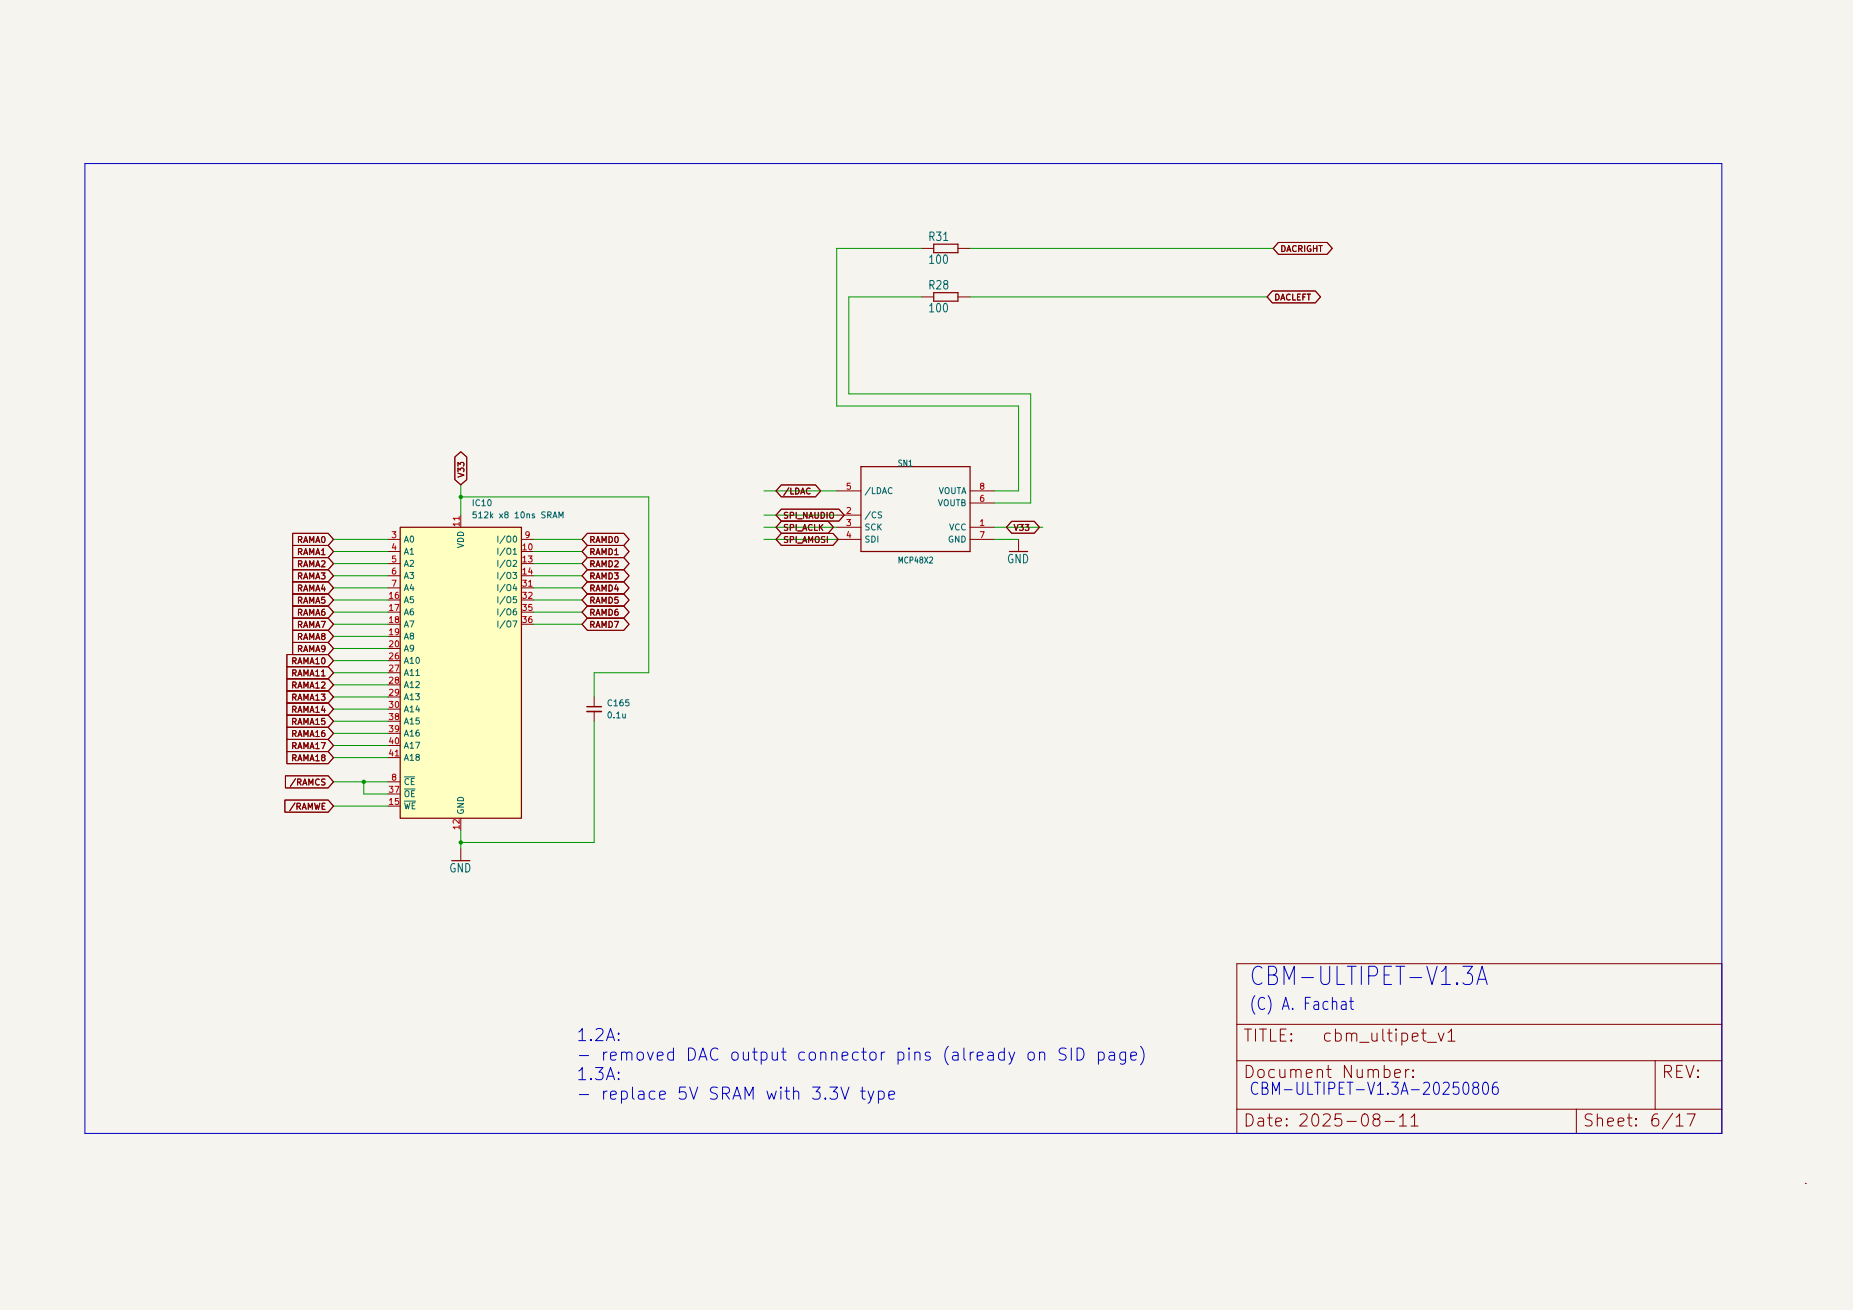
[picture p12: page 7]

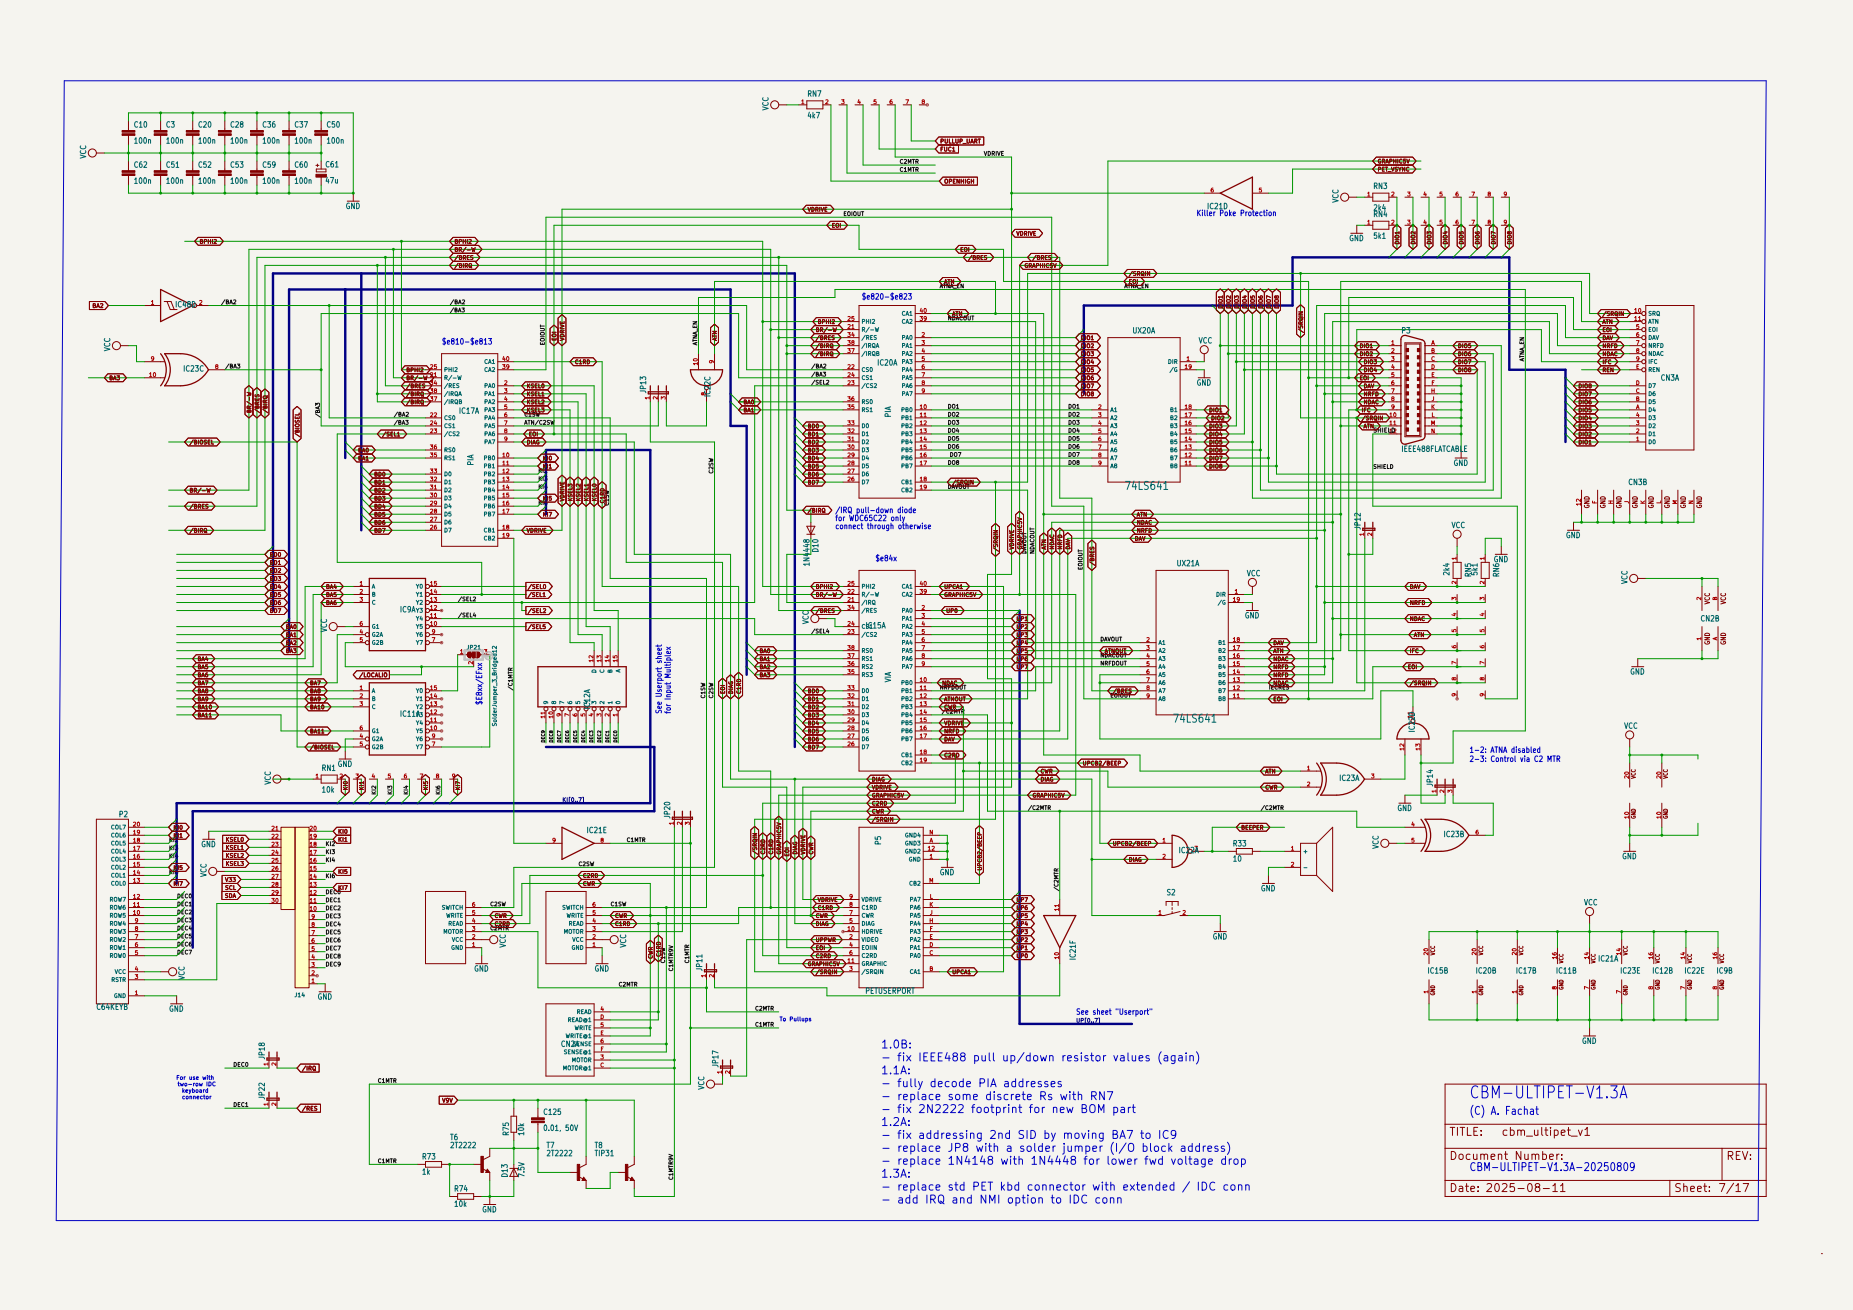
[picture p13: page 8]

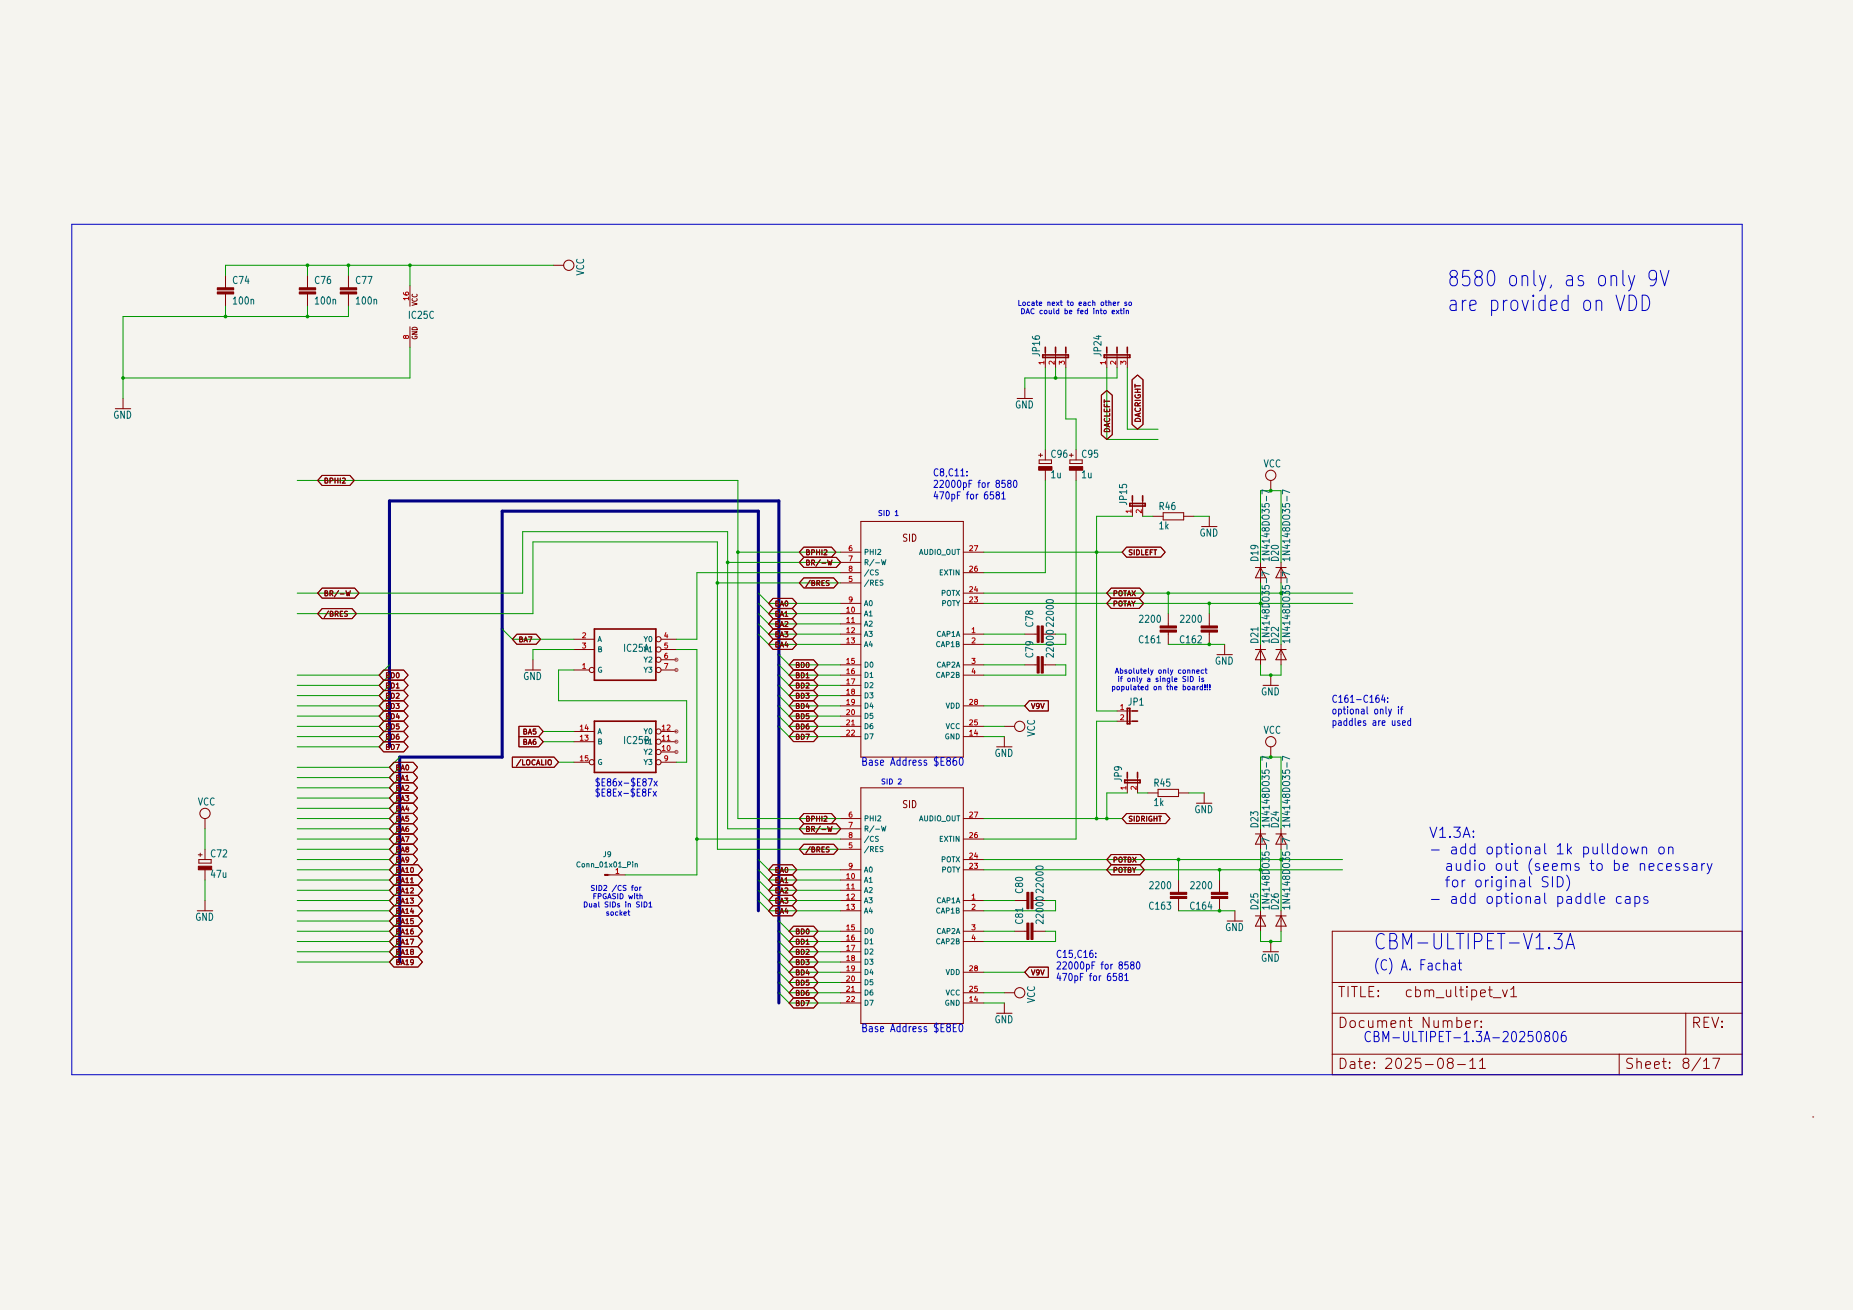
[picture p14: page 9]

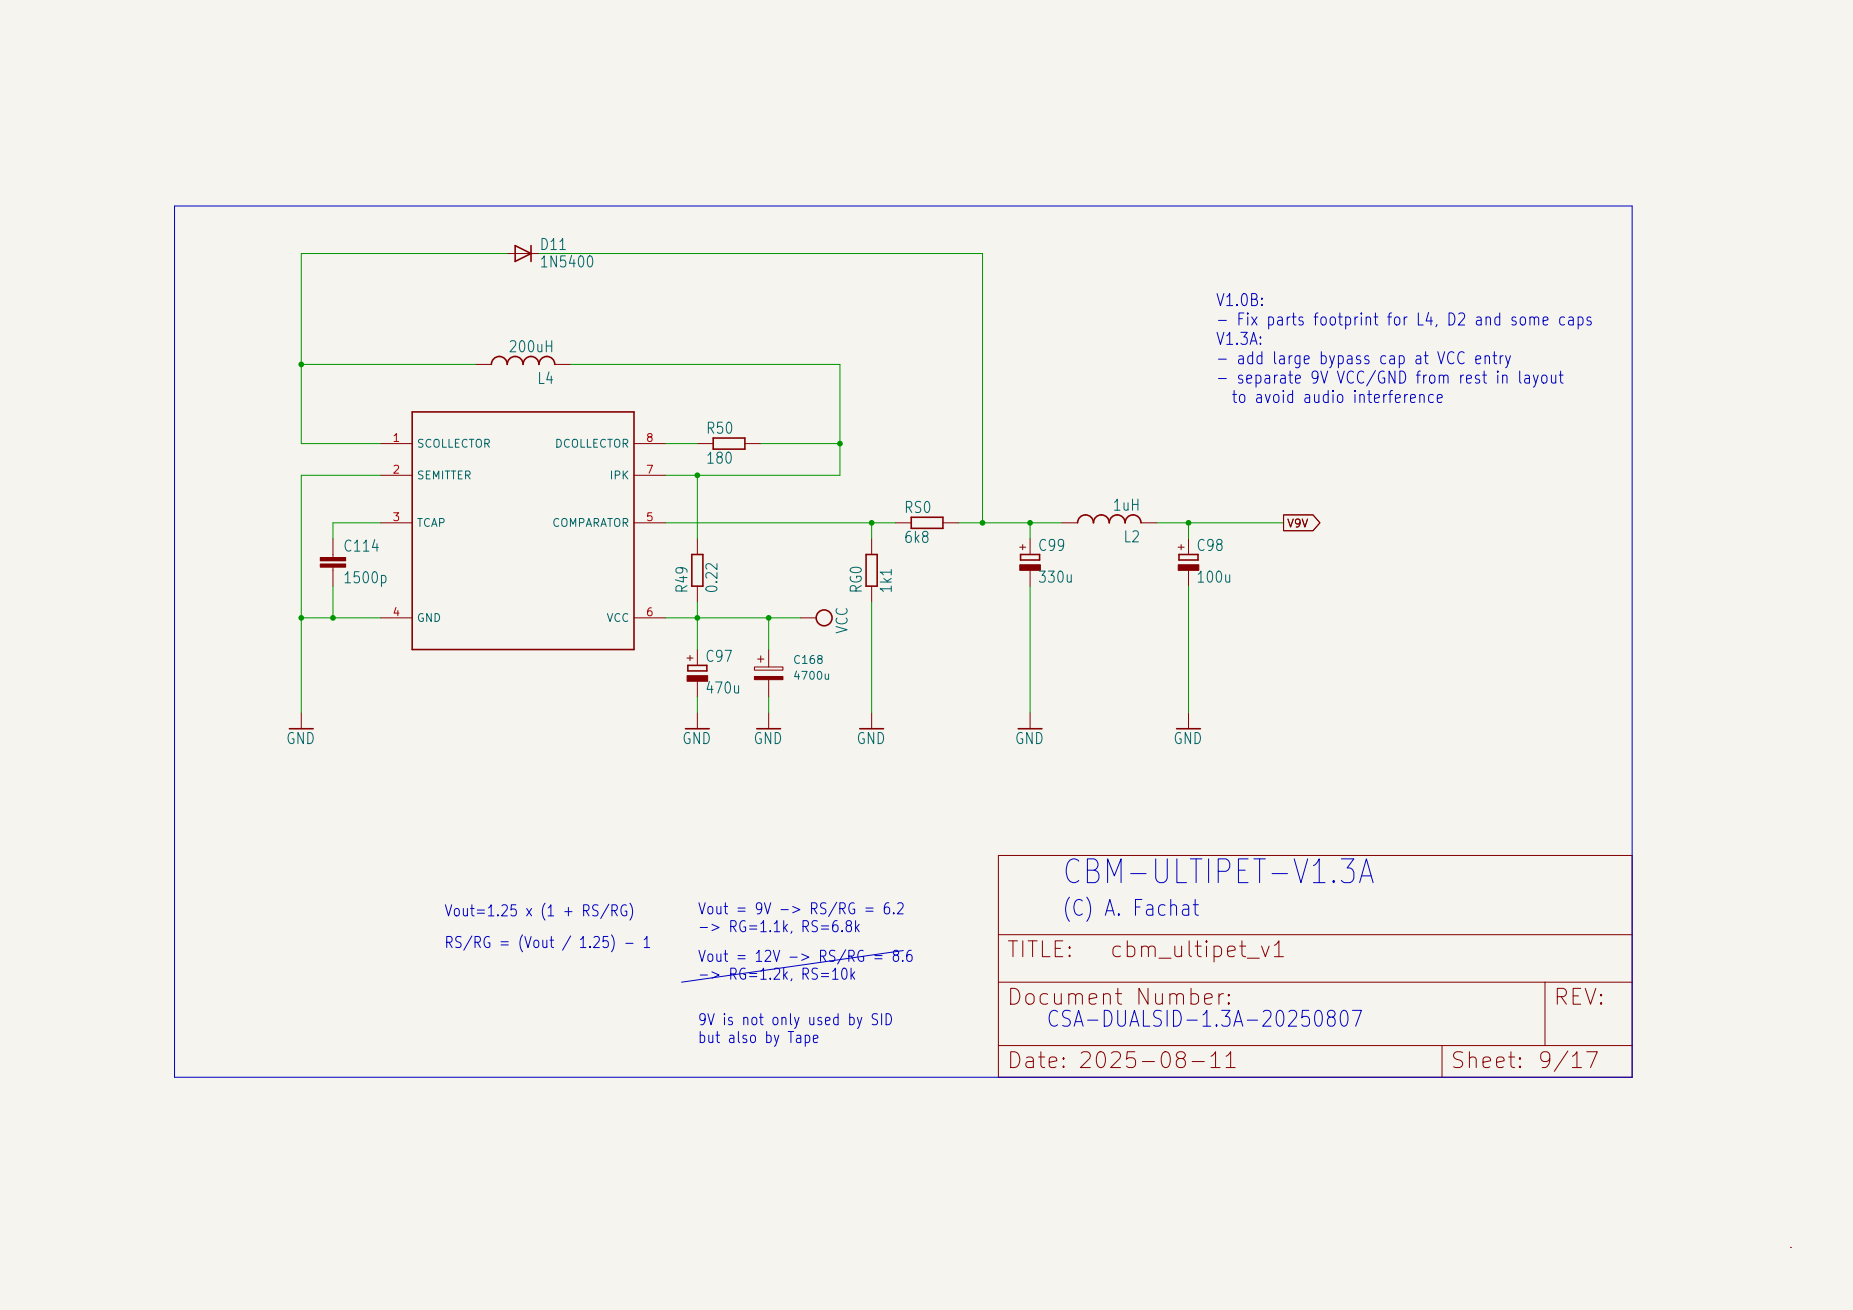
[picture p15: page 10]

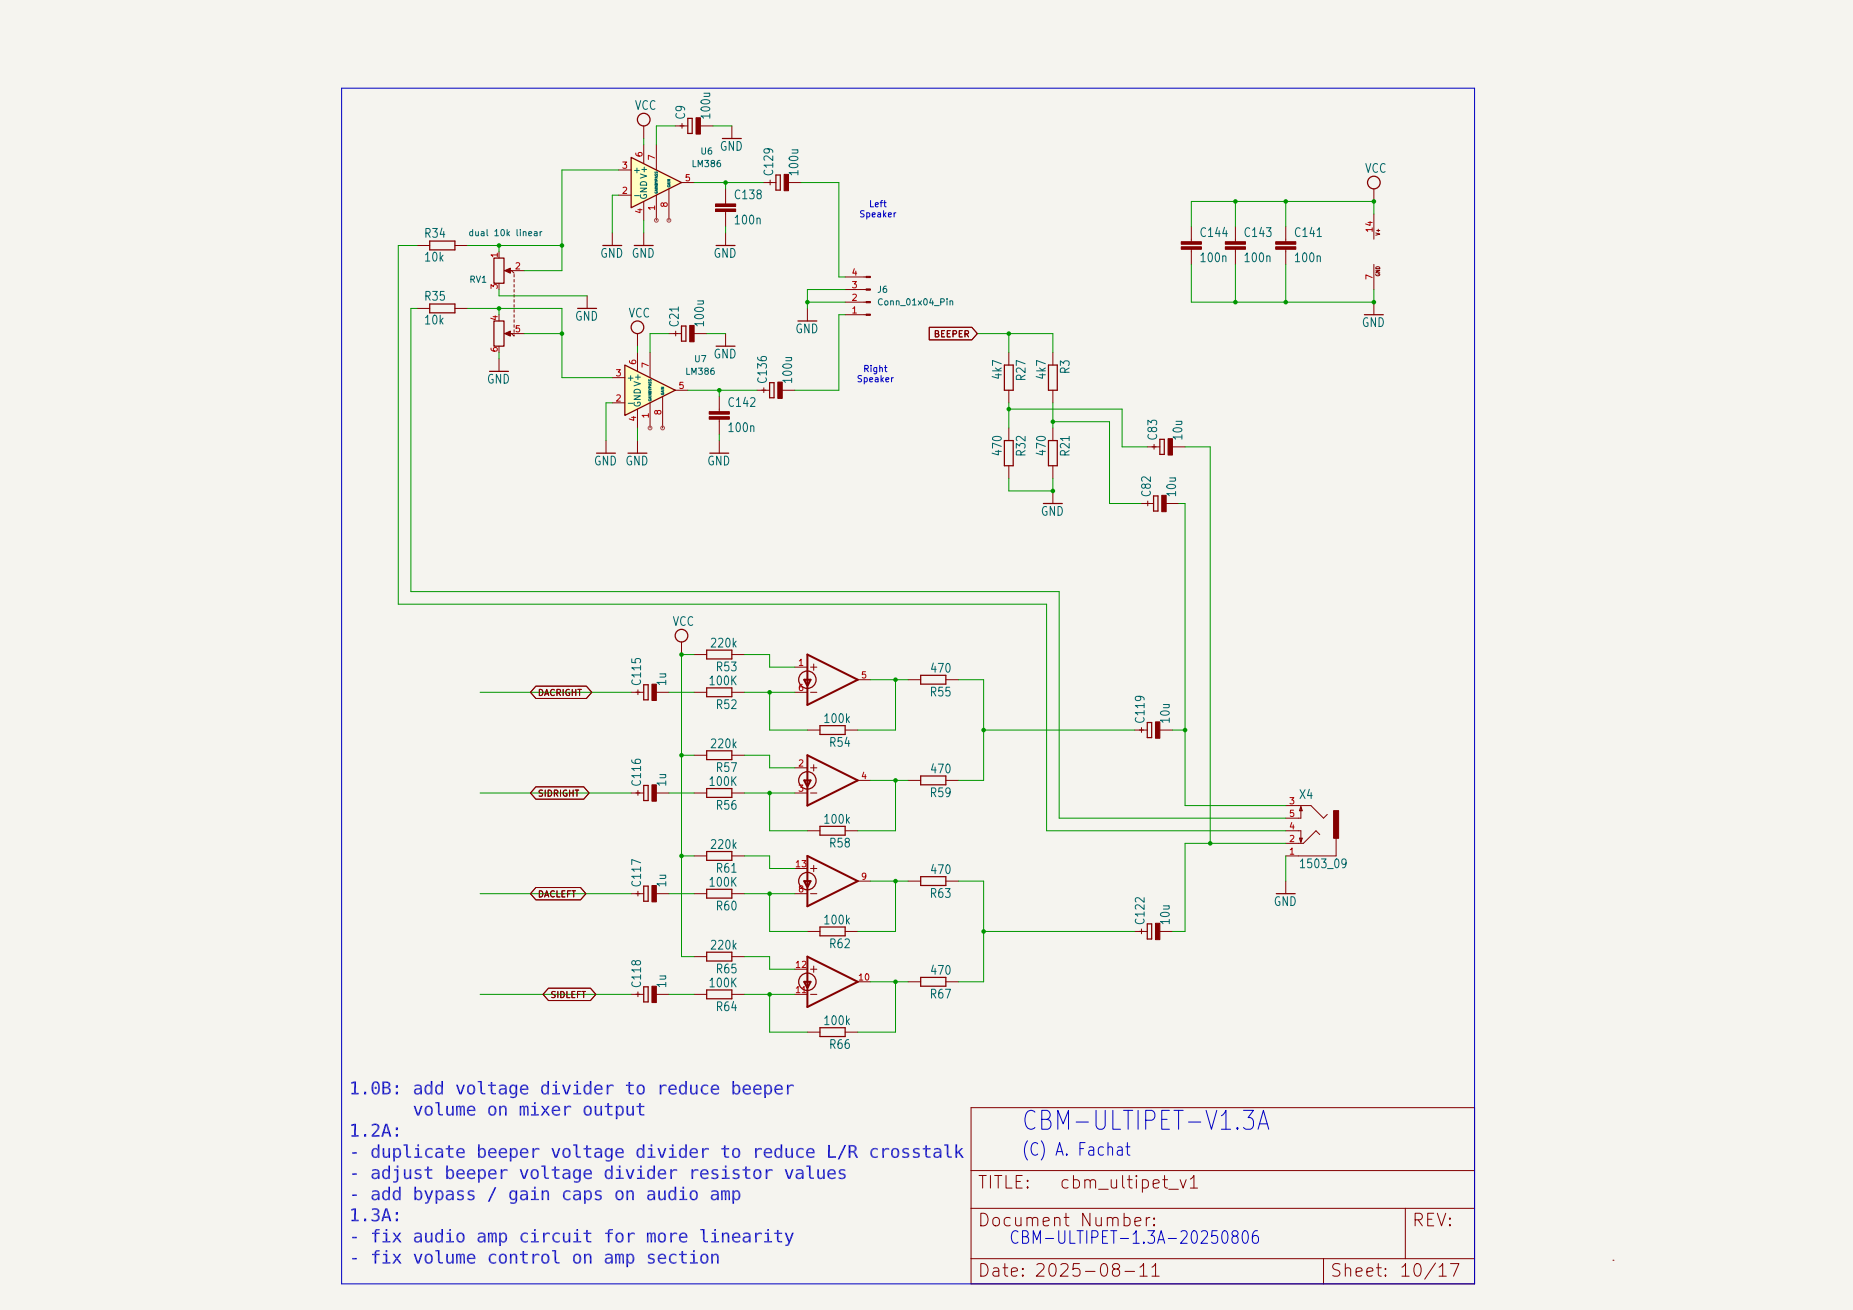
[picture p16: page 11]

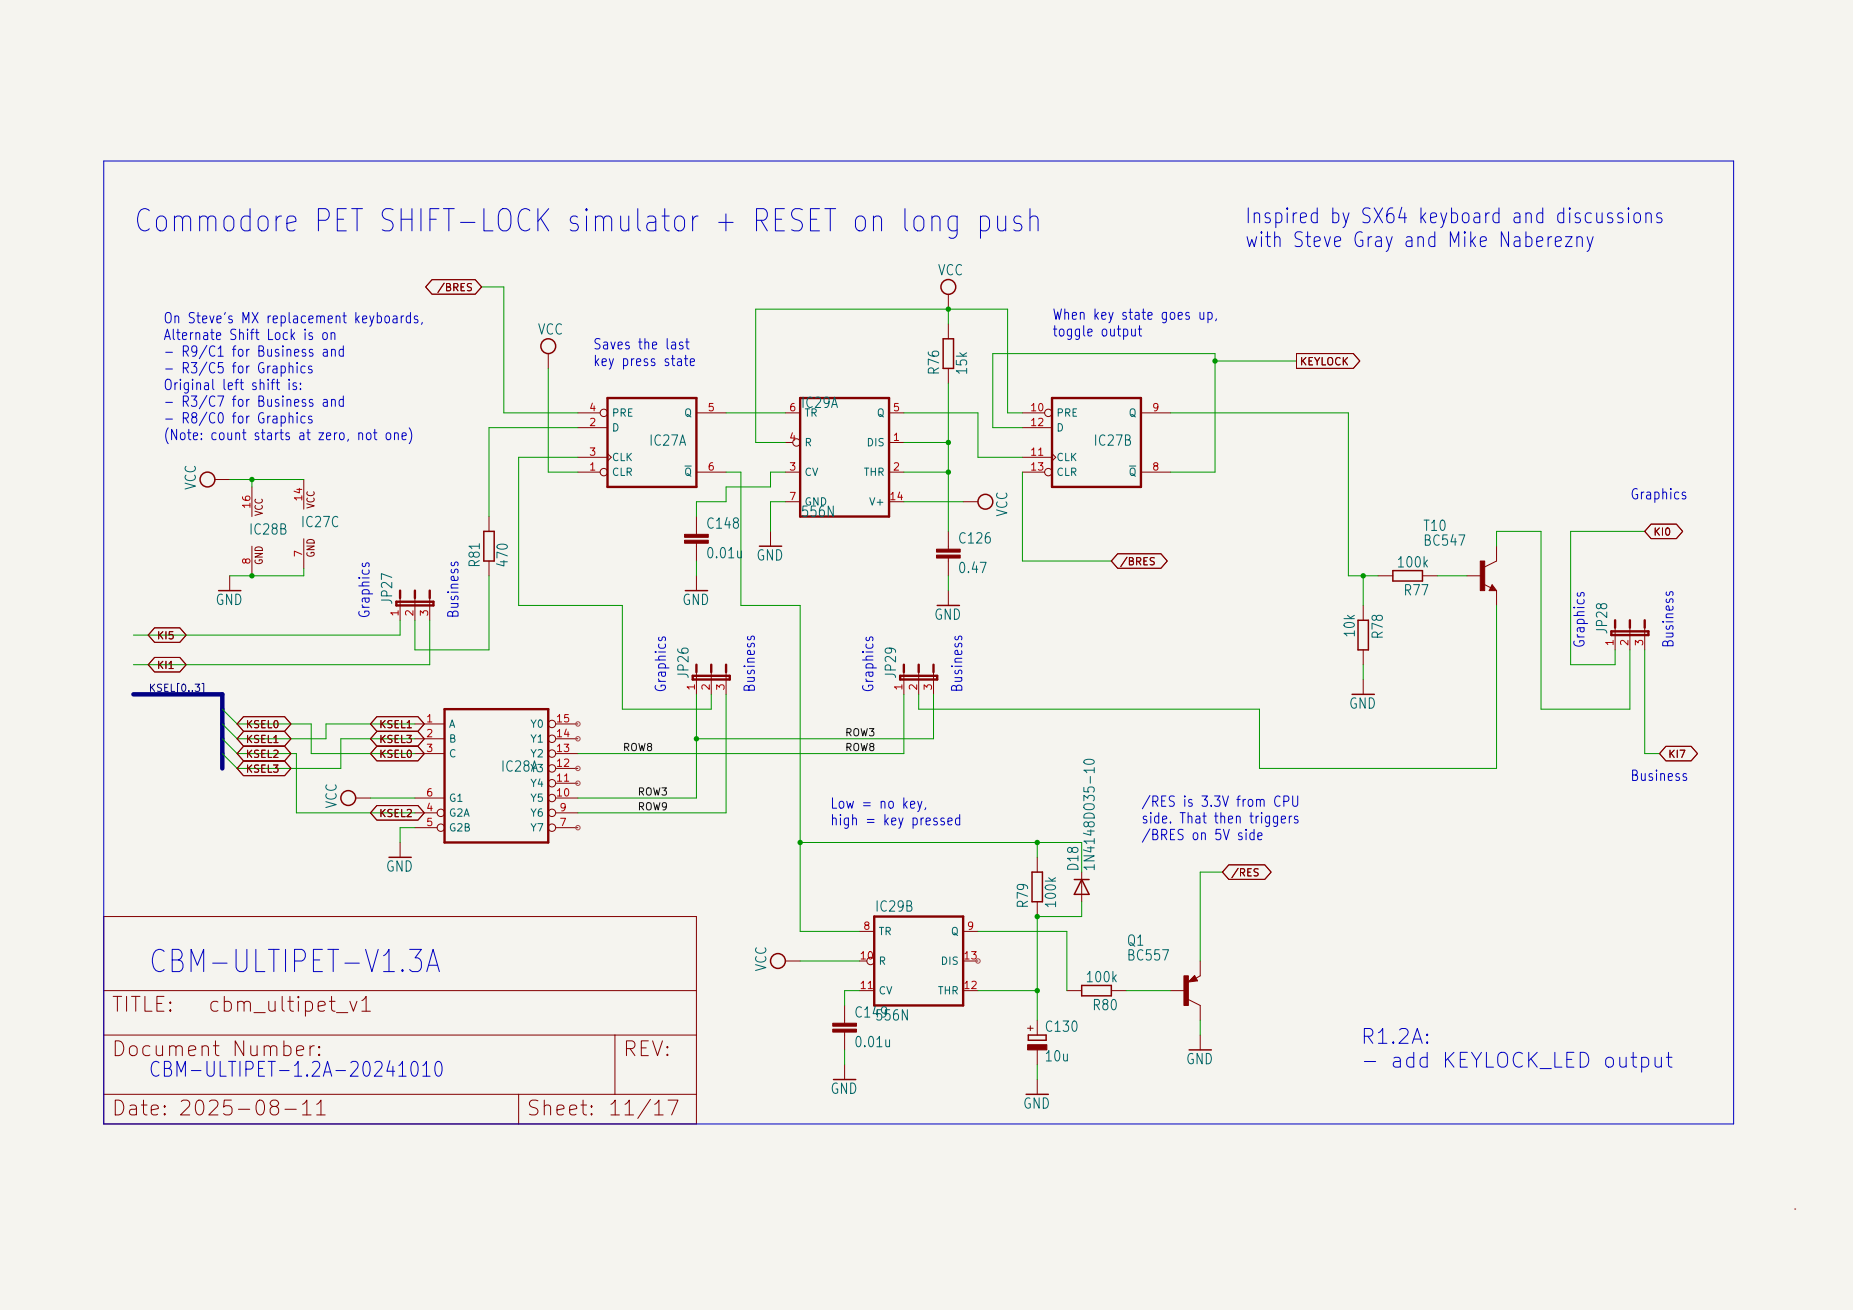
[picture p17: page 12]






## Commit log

2024-02-03 initial publish
    [A%2fV.kicad_sch, Bus.kicad_sch, CPU,_FPGA,_FRAM.kicad_sch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]
2024-02-03 fix a trace width
2024-04-03 Ultipet 1.0A final
    [A%2fV.kicad_sch, Bus.kicad_sch, CPU,_FPGA,_FRAM.kicad_sch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]
2024-06-19 publish ultipet 1.0a
    [bom.csv, designators.csv, positions.csv]
2024-06-19 ultipet 1.1a board
    [A%2fV.kicad_sch, Bus.kicad_sch, CPU,_FPGA,_FRAM.kicad_sch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]
2024-10-10 update SID footprints - still conflicting
    [SID.kicad_sch]
2024-10-10 diverse fixes
    [Bus.kicad_sch, CPU,_FPGA,_FRAM.kicad_sch, Keylock.kicad_sch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]
2024-10-13 various fixes as documented in github issues
    [CPU,_FPGA,_FRAM.kicad_sch, FastIEC.kicad_sch, PETIO.kicad_sch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]
2024-10-14 more fixes
    [Bus.kicad_sch, CPU,_FPGA,_FRAM.kicad_sch, Power.kicad_sch]
2024-10-17 clamp diodes for joysticks
    [A%2fV.kicad_sch, Smallbus.kicad_sch, Userport.kicad_sch]
2024-10-22 more layout work
    [Bus.kicad_sch, Power.kicad_sch, Smallbus.kicad_sch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]
2024-11-15 generic add digital video out connector
    [A%2fV.kicad_sch]
2024-11-17 improve mixer, reduce noise
    [Mixer.kicad_sch]
2024-11-17 add bypass caps for SD Cards
    [USB.kicad_sch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]
2024-11-17 add gerbers for 1.2a
2024-11-24 replace some ultipet specific TQFP with easier to solder parts
    [BOM_JLCSMT.csv, I2C,UEXT.kicad_sch, PETIO.kicad_sch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]
2024-11-25 as ordered for 3rd prototype
    [BOM_JLCSMT.csv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]
2024-11-28 updated bom
    [cbm_ultipet_v1-mouser.xlsx]
2024-11-28 cleanup bom files
    [cbm_ultipet_v1.2a-mouser.xlsx, cbm_ultipet_v1.csv]
2024-11-28 separate mouser BOM with zero qty lines removed
    [cbm_ultipet_v1.2a-bom.xlsx, cbm_ultipet_v1.2a-mouser.xlsx]
2024-12-01 add reverser board for expansion bus
    [reverseExpansionPort-B_Cu.gbl, reverseExpansionPort-B_Mask.gbs, reverseExpansionPort-B_Paste.gbp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]
2024-12-01 add note regarding reverser board
2024-12-02 add oscillator fix board
    [OscillatorFootprintAdapter-B_Cu.gbr, OscillatorFootprintAdapter-B_Mask.gbr, OscillatorFootprintAdapter-B_Paste.gbr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]
2025-01-05 bom redo
2025-01-13 fix boms, audio connector footprint
    [cbm_ultipet_v1.2a-bom.xlsx, cbm_ultipet_v1.2a-mouser.xlsx]
2025-01-26 update bom
    [cbm_ultipet_v1.2a-bom.xlsx]
2025-01-26 fixed power switch footprint that got replaced on some update
    [A%2fV.kicad_sch, Bus.kicad_sch, CPU,_FPGA,_FRAM.kicad_sch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]
2025-01-26 first work on r1.3
    [Mixer.kicad_sch, Power.kicad_sch, Smallbus.kicad_sch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]
2025-01-26 more work on 1.3
    [CPU,_FPGA,_FRAM.kicad_sch, I2C,UEXT.kicad_sch, SID.kicad_sch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]
2025-05-12 add Warning about kicad 9
2025-08-05 work on 1.3
    [A%2fV.kicad_sch, Bus.kicad_sch, CPU,_FPGA,_FRAM.kicad_sch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]
2025-08-06 work on r1.3
    [A%2fV.kicad_sch, CPU,_FPGA,_FRAM.kicad_sch, Mixer.kicad_sch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]
2025-08-06 more work on r1.3
    [Keylock.kicad_sch, SID.kicad_sch, UART.kicad_sch]
2025-08-06 preview for r1.3
    [A%2fV.kicad_sch, Bus.kicad_sch, FastIEC.kicad_sch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]
2025-08-06 add missing chg log for mixer
    [Mixer.kicad_sch]
2025-08-06 layout work on r1.3a
    [CPU,_FPGA,_FRAM.kicad_sch, VRAM,_DAC.kicad_sch]
2025-08-07 more layout work on r1.3
    [CPU,_FPGA,_FRAM.kicad_sch, FastIEC.kicad_sch, PETIO.kicad_sch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]
2025-08-07 fix DS1818 layout
    [Power.kicad_sch]
2025-08-09 add some jumper options, layout work
    [PETIO.kicad_sch, USB.kicad_sch]
2025-08-09 fix pcb outline
2025-08-10 new USB C conn; BOM work
    [A%2fV.kicad_sch, Power.kicad_sch]
2025-08-10 more work on BOM
2025-08-10 rename U refs to UX*
    [A%2fV.kicad_sch, CPU,_FPGA,_FRAM.kicad_sch, FastIEC.kicad_sch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]
2025-08-10 working on jlcpcb production files
    [BOM-cbm_ultipet_v1.csv, UART.kicad_sch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]
2025-08-11 cleanup folder
    [OscillatorFootprintAdapter-B_Cu.gbr, OscillatorFootprintAdapter-B_Mask.gbr, OscillatorFootprintAdapter-B_Paste.gbr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]
2025-08-11 some layout fixes, more parts
    [BOM-cbm_ultipet_v1.csv, CPU,_FPGA,_FRAM.kicad_sch, Keylock.kicad_sch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]
2025-08-11 update schem pdf and production files
    [BOM-cbm_ultipet_v1.csv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]
2025-08-28 add some footprints
2025-08-28 add test boards
    [BOM-FootprintTest.csv, BOM-HDMItest.csv, FootprintTest.kicad_pcb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]
2026-02-22 adding SID mirroring to schem
    [SID.kicad_sch]
2026-03-12 add sdcard breakout
    [sdcardext.kicad_pcb, sdcardext.kicad_sch]
2026-03-12 add part#, pullup for CD
    [sdcardext.kicad_pcb, sdcardext.kicad_sch]
2026-03-15 SD card and volumn poti test extension
    [BOM-sdcardext.csv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]
2026-05-08 add C64 restore
    [CPU,_FPGA,_FRAM.kicad_sch, PETIO.kicad_sch, SID.kicad_sch]
2026-07-07 new HDMI test with re-driver
    [BOM-HDMItest.csv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]
2026-07-26 new HDMI adapter with AC coupling
    [BOM-HDMItest.csv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]
2026-08-16 new HDMI adapter with SN75DP139
    [BOM-HDMItest.csv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]
2026-09-13 move sdcard to pcb_bits
    [BOM-HDMItest.csv, BOM-sdcardext.csv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]
2026-09-13 move HDMI test schems to pcb_bits
    [BOM-HDMItest.csv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]
2026-09-13 move footprint test to pcb_bits
    [BOM-FootprintTest.csv, FootprintTest.kicad_pcb, FootprintTest.kicad_sch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]
